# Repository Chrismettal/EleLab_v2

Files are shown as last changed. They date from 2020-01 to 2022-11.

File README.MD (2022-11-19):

# Elelab_v2 <!-- omit in toc -->

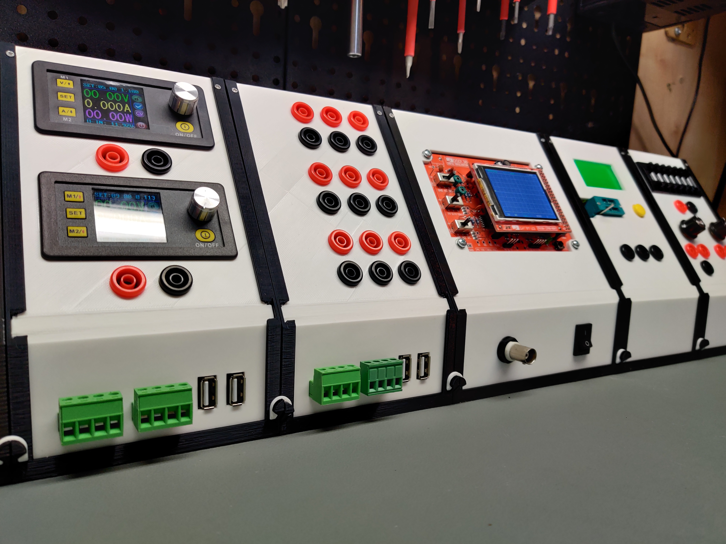
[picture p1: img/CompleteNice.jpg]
WholeSystem


## Table of contents <!-- omit in toc -->

- [Buying](#buying)
- [The concept](#the-concept)
- [The PCBs](#the-pcbs)
  - [Bus100 / Bus150](#bus100--bus150)
  - [PowerFeed](#powerfeed)
  - [Frontpanel\_a](#frontpanel_a)
- [The modules](#the-modules)
  - [Supplies](#supplies)
  - [Supply from ATX/SFX](#supply-from-atxsfx)
  - [Supply from XT60/Barrel](#supply-from-xt60barrel)
  - [Supply from Meanwell PSU](#supply-from-meanwell-psu)
  - [Supply from Bosch 18 V Battery](#supply-from-bosch-18-v-battery)
  - [Lab PSU fixed](#lab-psu-fixed)
  - [Lab PSU variable](#lab-psu-variable)
  - [Oscilloscope DSO138](#oscilloscope-dso138)
  - [Resistor decade](#resistor-decade)
    - [Performance](#performance)
  - [Component tester](#component-tester)
  - [Raspberry Pi](#raspberry-pi)
  - [Display](#display)
  - [Electronic Load](#electronic-load)
  - [Signal generator](#signal-generator)
  - [Audio amplifier / signal tracer](#audio-amplifier--signal-tracer)
  - [TS100 Soldering station](#ts100-soldering-station)
- [Tips and tricks](#tips-and-tricks)

This is a low cost, modular elctronics lab system for hobbyists.
The customizable modules include fixed and variable power supplies, measurement tools, component testers and much more.
Everything in here is done with open source software, including FreeCAD for all the 3d printable files and KiCAD for the PCBs.
I have made a set of modules already and am in the process of creating many more. Raw PCB project files, Gerbers and FreeCAD projects are all uploaded here for your customizing needs, while the finished modules are uploaded to Prusaprinters. Please be sure to upload any remix you do as it might be useful for others and especially myself!

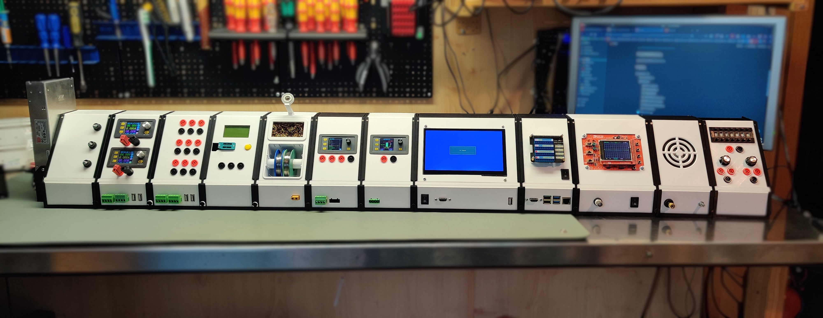
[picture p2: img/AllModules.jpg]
AllModules


The system features a set of backpanel bus PCBs as well as panel breakout PCBs. While the backpanel bus is not neccesary, it keeps the system modular, hot swappable and tidy. You can have the gerbers manufactured for cheap at your favorite chinese PCB house or just shoot me a message. I might have spares.

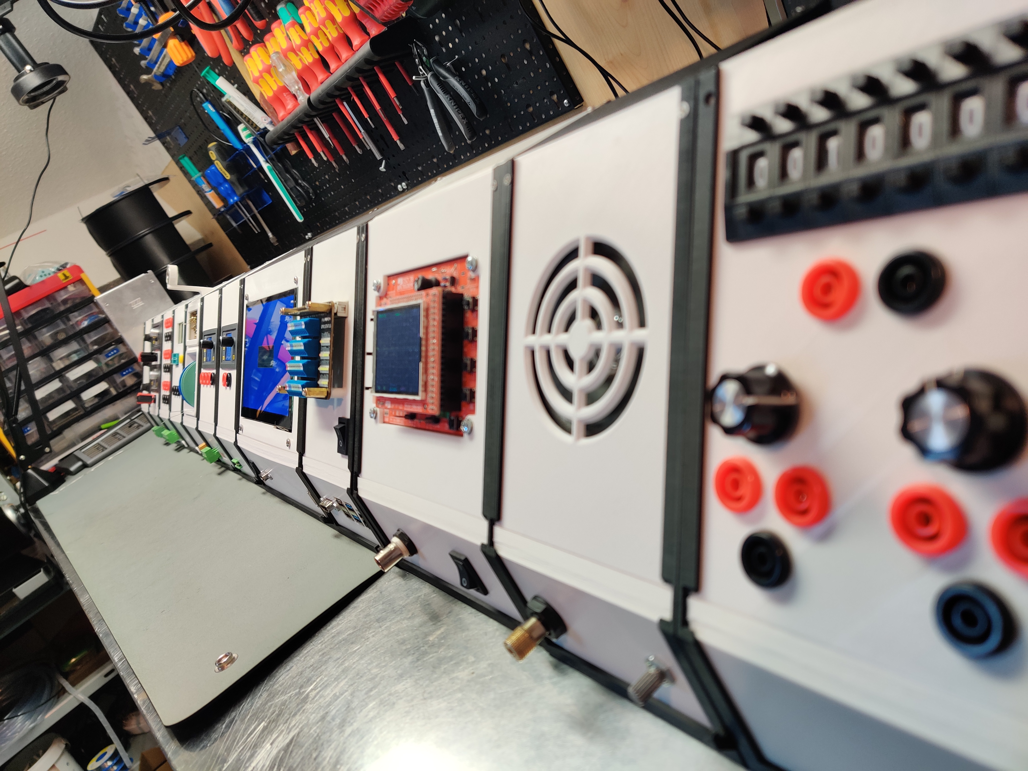
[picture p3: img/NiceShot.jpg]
NiceShot


Finished modules for printing yourself for any module can be found [here in the Prusaprinters collection](https://www.prusaprinters.org/social/13425-chrismettal/collections/14323).
For most of the modules a printbed of 160x160mm and 175mm of height is sufficient, but the ATX and SFX module require print bed sizes of up to 250mm width (Prusa MK2 and up dimensions). I printed all of the modules in PLA and just to speed things up i used a 0.6mm nozzle but that is not required at all.

Showcase

**If you like my work please consider [supporting my caffeine addiction](https://gitlab.com/Chrismettal#donations)!**

## Buying

All PCBs as well as 3D printed parts are now stocked at Tindie!



## The concept

The system consists of 3 basic sizes of modules, 100mm, 150mm and 200mm. For the 100mm and the 150mm frame there is a backpanel bus that interconnects the modules together for power delivery. The 200mm frame uses two of the 100mm PCBs.

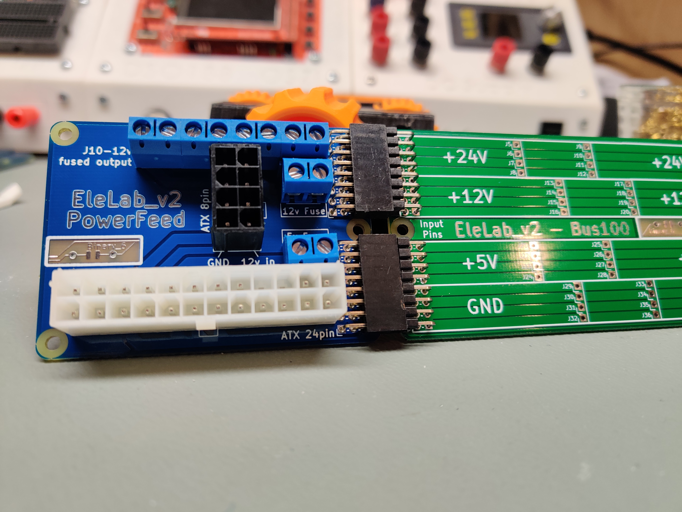
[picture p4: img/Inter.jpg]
Interconnects

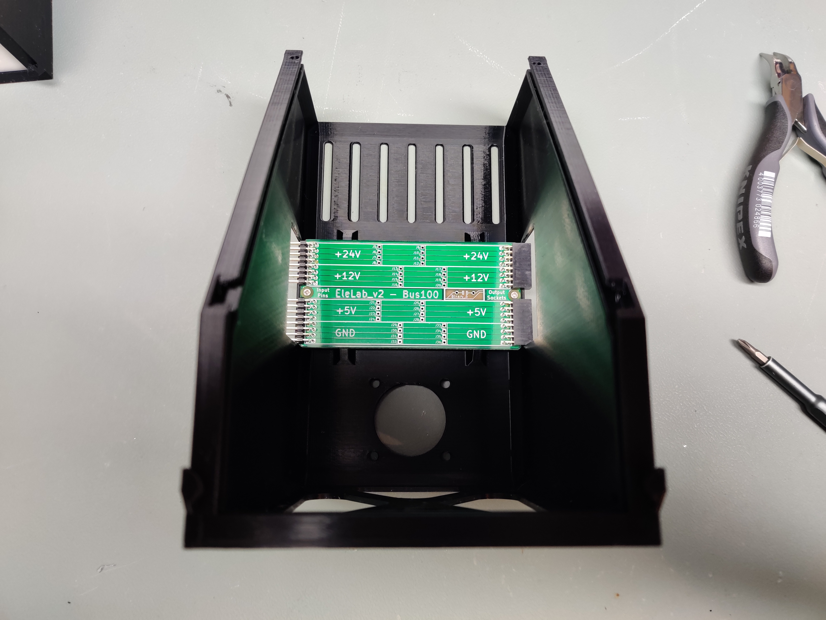
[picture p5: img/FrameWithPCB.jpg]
FrameWithPCB


For the modules we usually use one of the 3 base sizes and punch holes in the upper and/or lower front panel to suit our mounting needs. This can be done in FreeCAD by modifying the BaseXXX file or a finished module that best fits your new module. Alternatively you can also just edit the .stl files in the editor of your choice.

The backpanel bus is equipped to transfer 24 V, 12 V and 5 V (and GND, duh), which we feed into the system by one of the "Supply" modules. At the moment i made an SFX-PSU supply module (supplying 12 V and 5 V) and one with a 5.5mm barrel jack and XT60 jack (Using 24 V supplies and step-down converters for 12 V and 5 V). Both of these supply modules feature the PowerFeed PCB to feed into the backpanel bus. Because 24 V is rarely needed for most of the modules, the easiest and safest way to use this system is the SFX module, which just plugs into the PowerFeed PCB.

Obviously you can just run wires between the modules and omit the backpanel bus, but it will probably make me a little sad.

If you are using the bus, individual modules just plug into each other to form a single unit. 

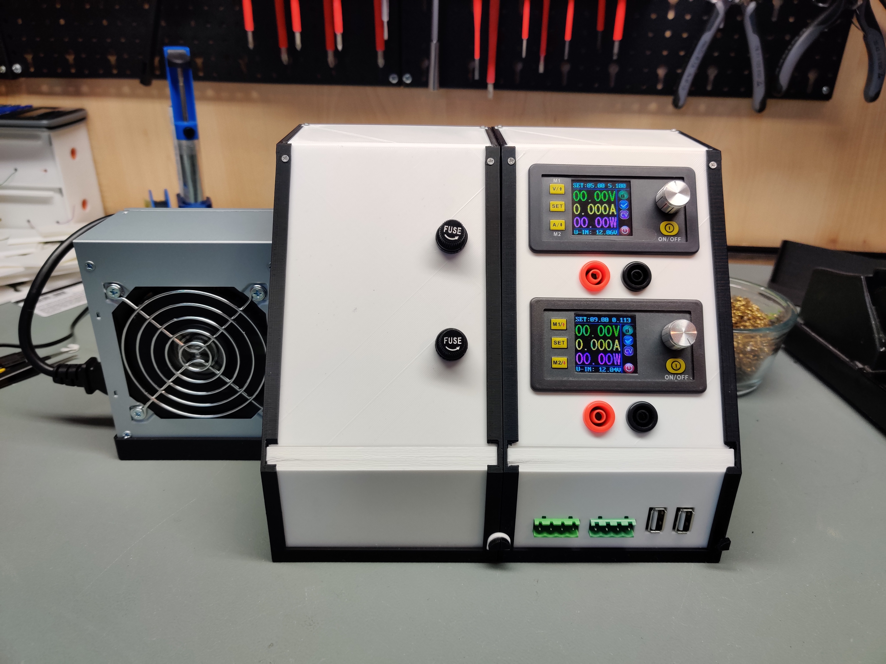
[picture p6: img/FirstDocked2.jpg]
FirstDocked2


With 2 little printed clips you can secure the modules together so they don't seperate during the occasional earthquake or lab-ragequit.

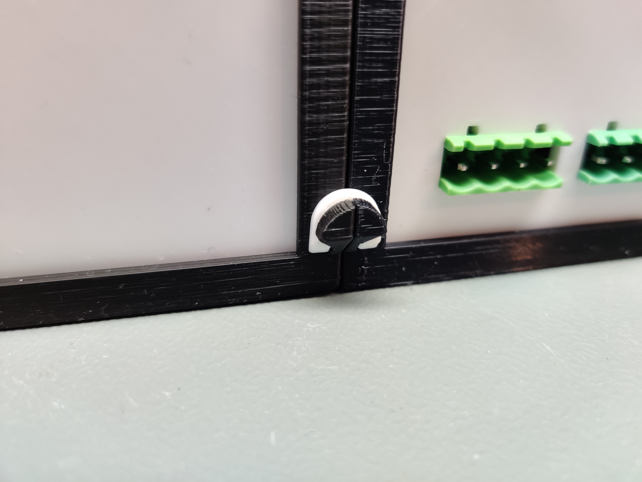
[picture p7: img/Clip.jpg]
Clip


Almost none of the 3d printable pieces require supports. The frame of each module has integrated supports at one position, that you will need to cut away after printing:

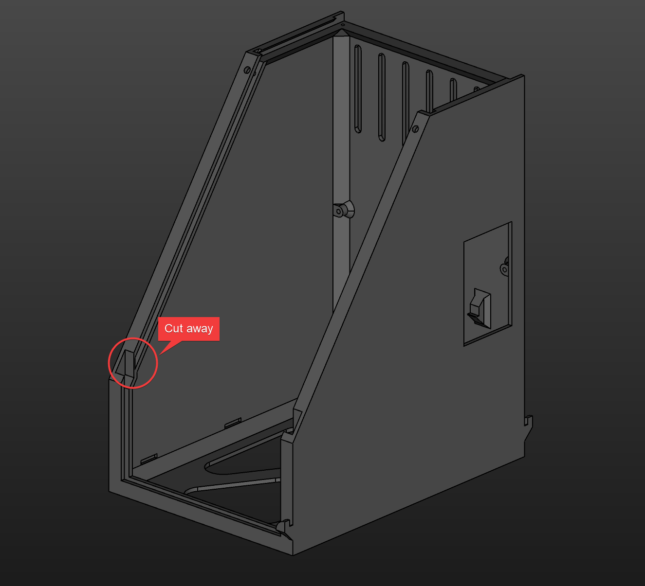
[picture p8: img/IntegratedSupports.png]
IntegratedSupports


## The PCBs

All of the PCBs can be cheaply manufactured in China (trust me, it's easier and cheaper than you think) or sometimes i even have spares left, if you shoot me a message.

### Bus100 / Bus150

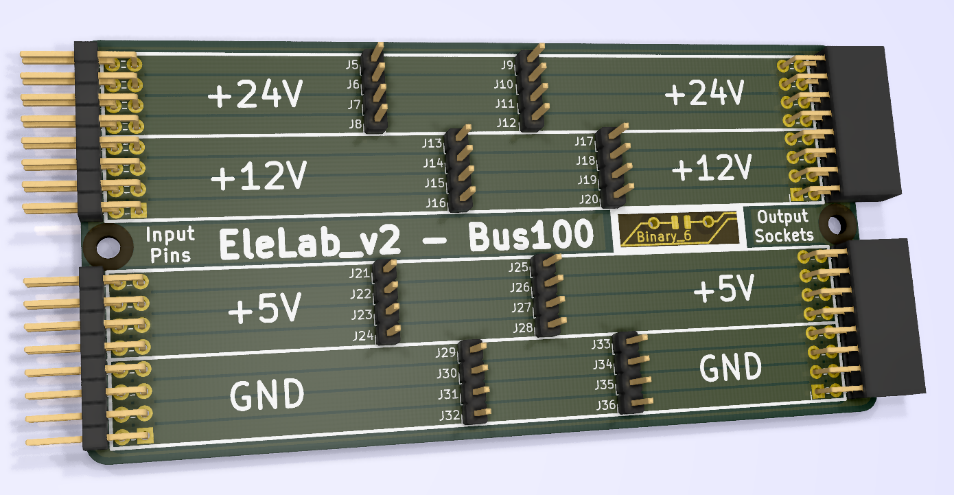
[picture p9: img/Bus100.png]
Bus100


This is the basic backpanel bus to link individual modules together. Though optional, it greatly enhances your experience in building this system.

**Parts:**

- 2pcs 2.54mm Pinheader right angle 2x8 female
- 2pcs 2.54mm Pinheader right angle 2x8 male

### PowerFeed

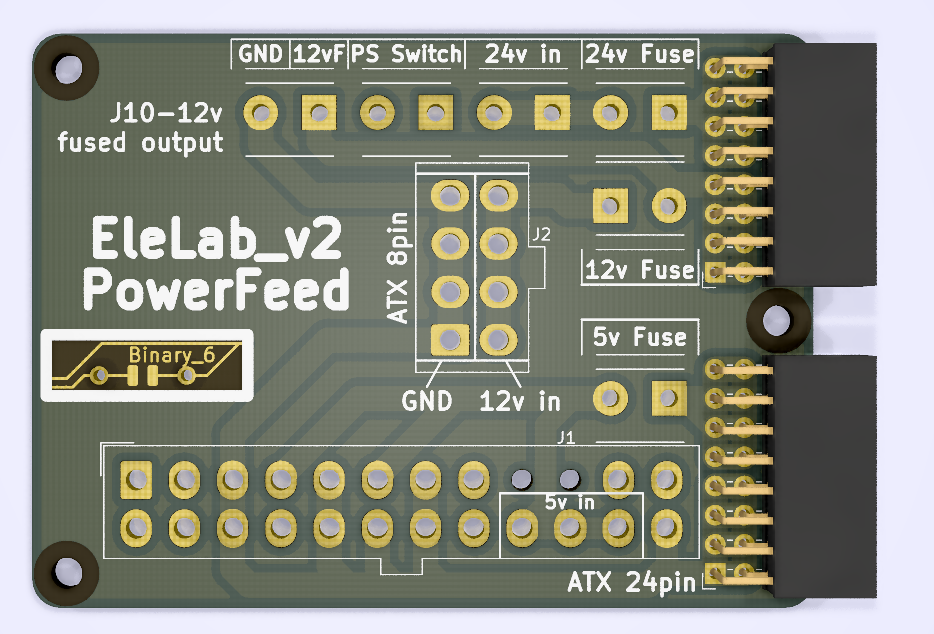
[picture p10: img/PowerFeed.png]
PowerFeed


This is the main infeed to connect your power supply to the backpanel bus and feed into the modules. It packs jacks to plug in your SFX supply, screw connectors for external fuses, and a breakout for the SFXs standby switch. Alternatively you could wire up your supplies directly to the spots marked as 24V, 12V and 5V respectively without using ATX connectors.

Using a PC supply, 12 V are supplied through either a 4 or 8 pin CPU header power plug. You cannot use the 8-pin GPU plug on your high end ATX PSU.

**Parts:**

- 24 Pin 4.2mm ATX Connector standing 
-  8 Pin 4.2mm ATX Connector standing
- 6pcs 5.08mm 2 Pin screw terminal (The blue cheap ones, optional though)

### Frontpanel_a

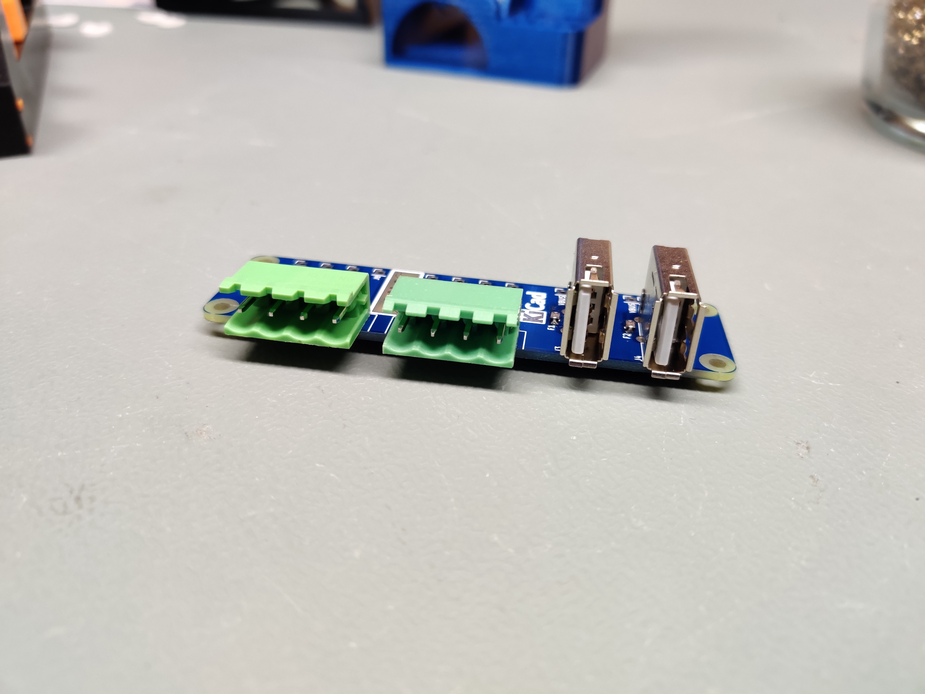
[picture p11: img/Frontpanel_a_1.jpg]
Frontpanel_a


Here we have the basic front panel breakout with industry style screw-plug connectors and USB jacks. The USB Jacks have a 0805 footprint in line with the 5 V rail so you can optionally install a tiny polyfuse in there. The data lines of each USB port are broken out so you can either use it for normal data transfer, or do whatever the best quick charge port configuration on the data lines is today. (for example bridging D+ and D- to put old Android phones into quick charge mode)

**Parts:**

- 2pcs 5.08mm pcb screw terminal block 4 pin
- 2pcs standing vertical USB Ports
- 2pcs 0805 polyfuse 1.1A (Or your desired amperage)

## The modules

### Supplies

No matter what Infeed you use, you should aim for around 100 - 150 W of power in general. I use a 24 V,  150 W power supply to infeed into my system. For PC supplies you should watch for the individual rail current, as a PSU might show 5 A of 12 V, but split over 5 rails, so if you only use one rail you will only get 1 A out of your PSU.

### Supply from ATX/SFX

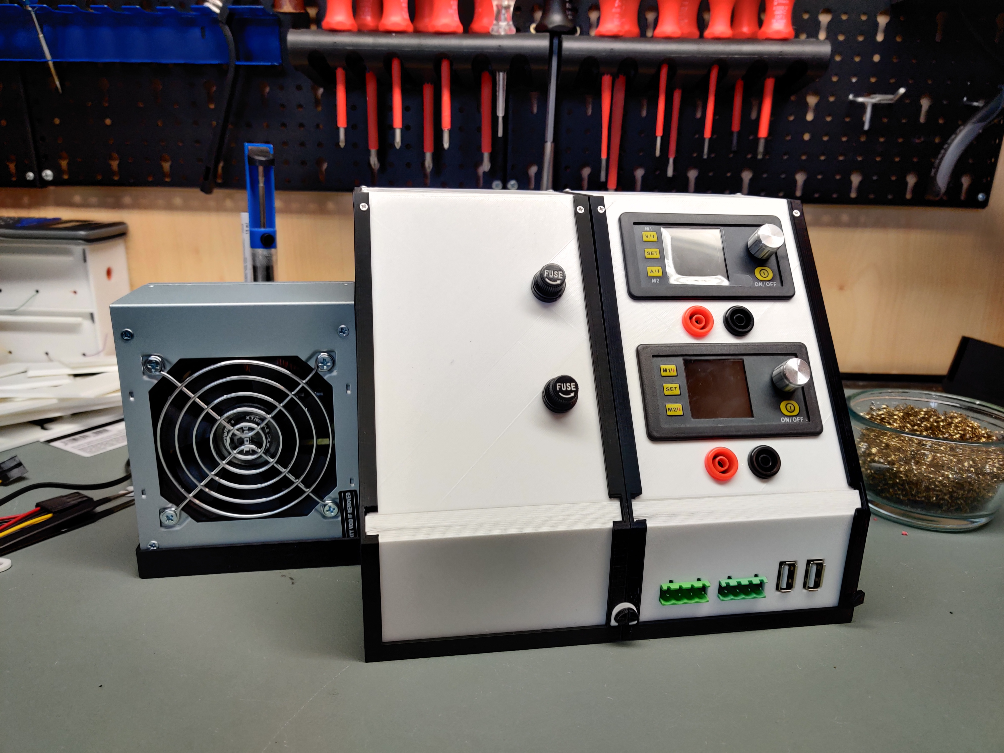
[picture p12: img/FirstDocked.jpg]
SFX


The easiest way to supply power to your EleLab is to use a regular ATX or SFX computer power supply. Using the PowerFeed PCB you can plug in the 24pin and 8pin connectors of your PSU directly into the backpanel bus. The module is preconfigured to use fuses for the 12 V and 5 V rails. You could install a switch for the PowerON PSU signal but i usually just bridge it completely so i switch the EleLab on and off by the main power switch on the back of the PSU.

Make sure the fan of your PSU is exposed as in the picture as not to overheat your poor PSU.

In the picture you see me build the SFX version of the module, the ATX version is printing at the time of writing this and is not tested yet.

**Parts:**

- PowerFeed PCB
- 2pcs screw in fuse holder panel mount
- SFX PSU of your choice
- 5pcs M2x8 self tapping screws

### Supply from XT60/Barrel

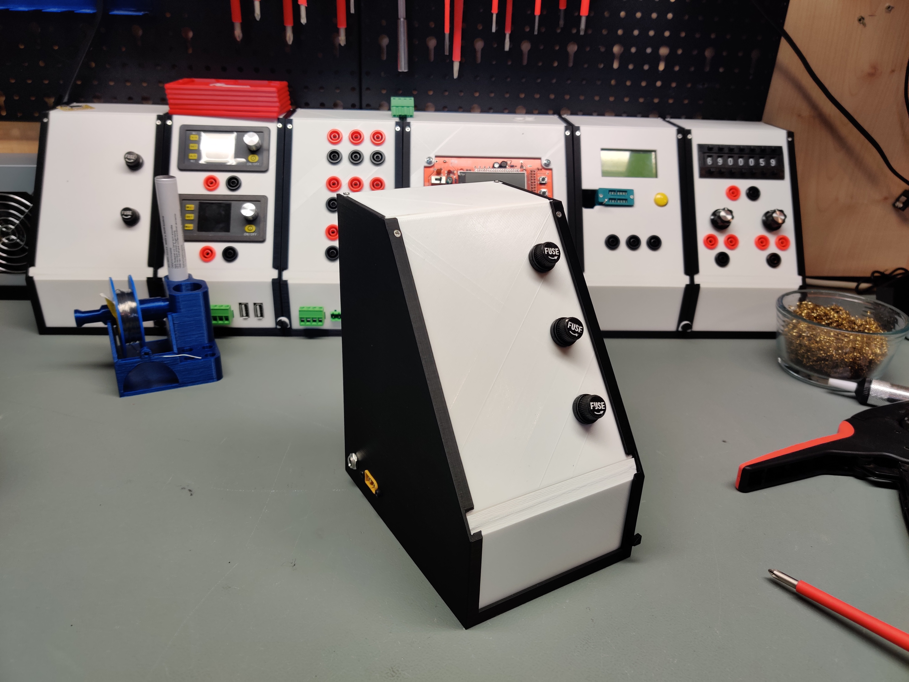
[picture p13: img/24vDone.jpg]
24vDone


With this supply module you can use any external 12 V or 24 V Power supply you want. You could even plug in some batteries with the XT60 jack!
This module however needs some beefy DC-DC step-down converters to create the 5 V rail, as well as the 12 V rail if you are using a 24 V supply. 
There is a printable tray that just snaps into the bottom, capable of carrying two of these types of step down converters:

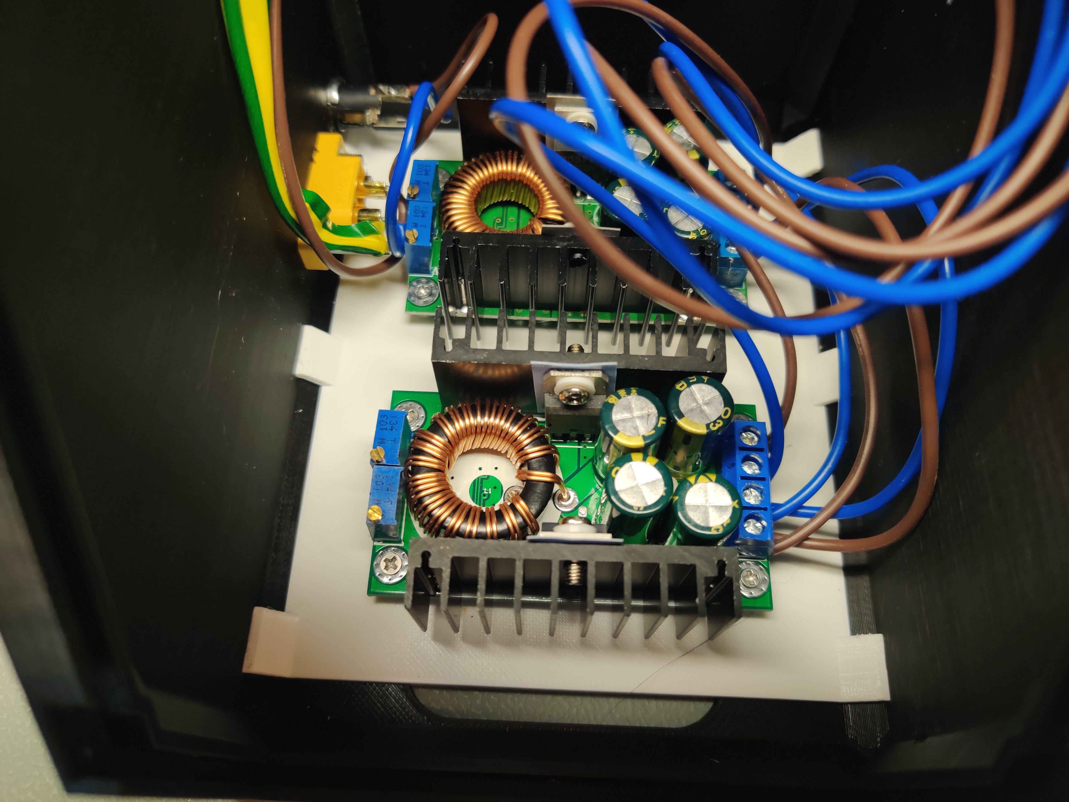
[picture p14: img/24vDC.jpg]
24vDC


These are readily available from china for a few bucks if you search for "step-down XL4016" on ebay. XL4016 is the name of the IC but it's the closest to a part number we get.

One of the converters will be set to output 5 V and one to output 12 V, when you supply the module with 24 V DC. This will give you all 3 voltages on the backpanel bus. The modules can also be configured for current limiting, which I set to 2 A each.

**Parts:**

- PowerFeed PCB
- 3pcs screw in fuse holder panel mount
- 2pcs DC-DC Step down converters XL4016
- 9pcs M2x8 self tapping screws

### Supply from Meanwell PSU

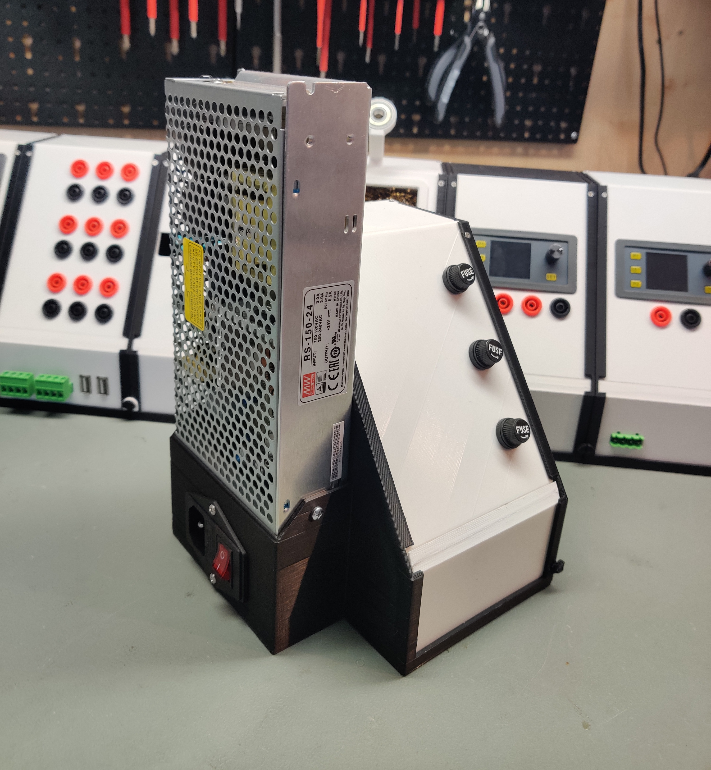
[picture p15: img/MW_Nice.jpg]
MWNice


Using the same step down converters, but this time using an internal PSU, the Meanwell module directly integrates a high quality supply into your EleLab. 
Since you will need to wire up mains voltage i can NOT show you how to do this. 
The Module uses an IEC C14 plug with integrated switch and fuse. Can't really find an exact name to google for.

The Meanwell supply should be a 24 V one, preferably the 150 W model, using the step down converters to step the voltage to 12 V and 5 V respectively.

**Parts:**

- PowerFeed PCB
- 3pcs screw in fuse holder panel mount
- 2pcs DC-DC Step down converters XL4016
- 9pcs M2x8 self tapping screws
- 4pcs M3x5 metric screws
- Meanwell RS-150-24
- IEC C14 Plug with switch and fuse

### Supply from Bosch 18 V Battery

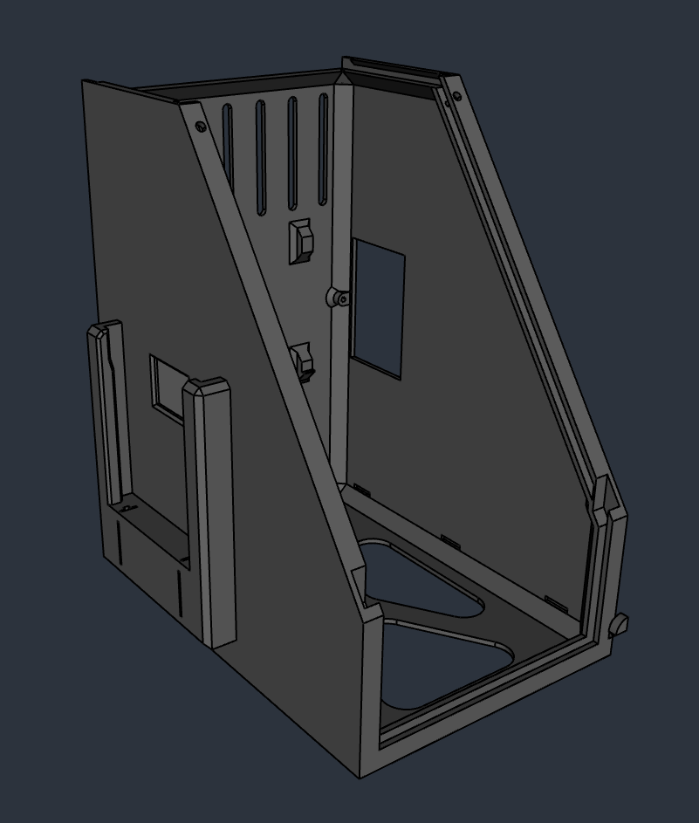
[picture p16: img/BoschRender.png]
BoschRender


BoschPurple

With this module you can use your 18 V Bosch batteries to supply a portable lab system. It also uses the same step down converters for rails of 18 V - 12 V and 5 V. Additionaly you will need two locking blade edge connectors. These are widely used in the car industry for confectionable plugs. The part number I found was “8KW048056-033” for a 6.3mm blade with 2.5mm² wire capacity.

Please note that 18 V Bosch batteries do NOT have over discharge protection built into the pack and can take damage if you run them below their specified "empty" point! Always watch the meter on your battery and make sure to use them in a healthy range. 

The edge connectors are slid in from the inside of the case and lock into place.

**Hint:** see also [standalone version](https://www.prusaprinters.org/prints/109595-bosch-18-v-battery-powerbank-power-supply)

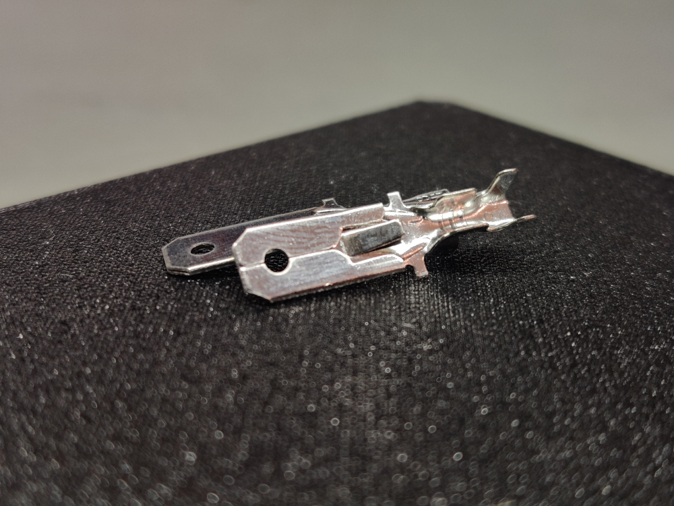
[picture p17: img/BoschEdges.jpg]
BoschEdges


**Parts:**

- PowerFeed PCB
- 3pcs screw in fuse holder panel mount
- 2pcs DC-DC Step down converters XL4016
- 9pcs M2x8 self tapping screws
- 2pcs “8KW048056-033” connectors
- Bosch 18 V battery

### Lab PSU fixed

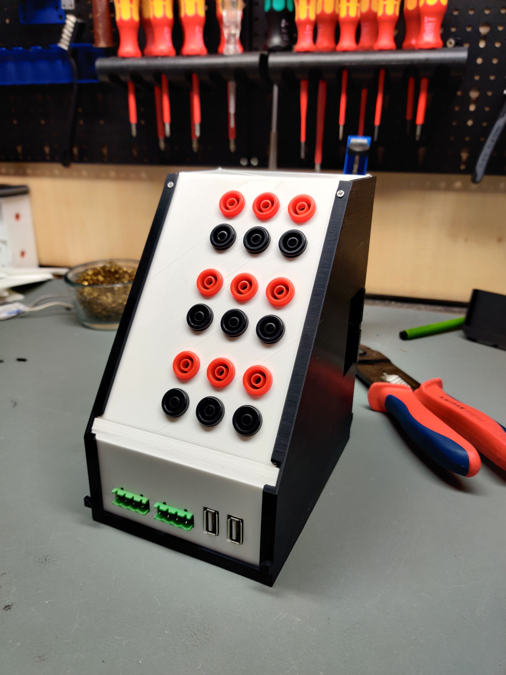
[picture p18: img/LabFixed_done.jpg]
LabFixed


The first actually usable module is a power breakout for your 5 V, 12 V and optionally 24 V rails. Using cheap chinese banana jacks with 12mm OD all rails can be accessed. In the front we use the Frontpanel_a PCB to have connections beside the banana jacks. Which terminal you connect to which rail is only dependend on your preferences. Obviously make sure to not reverse polarity on the USB ports or risk frying something. 

Here you can see the spagetthi wiring behind mine:

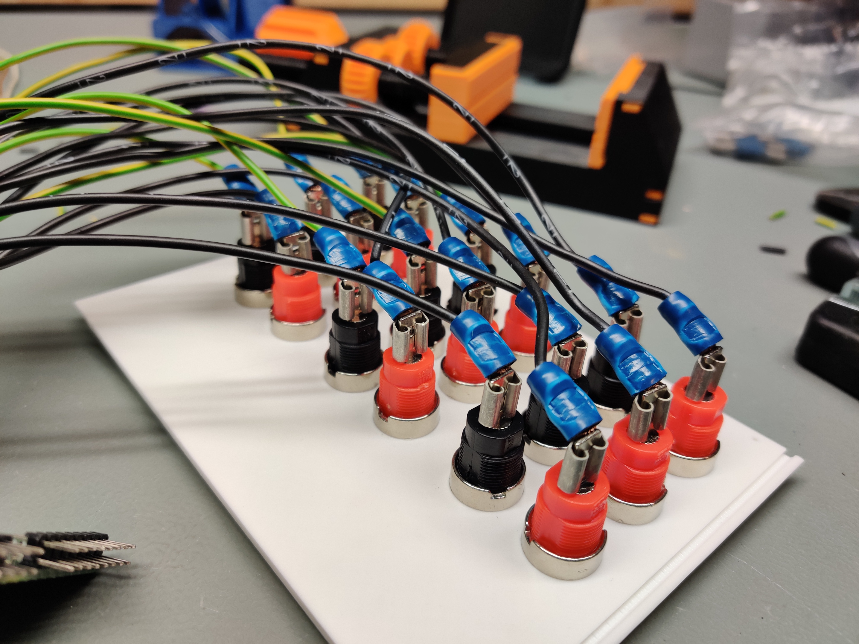
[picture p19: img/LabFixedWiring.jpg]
LabFixedWiring


Be sure to bend over your connectors as seen here as there is not extremely much room for the upper front panel to slide down:

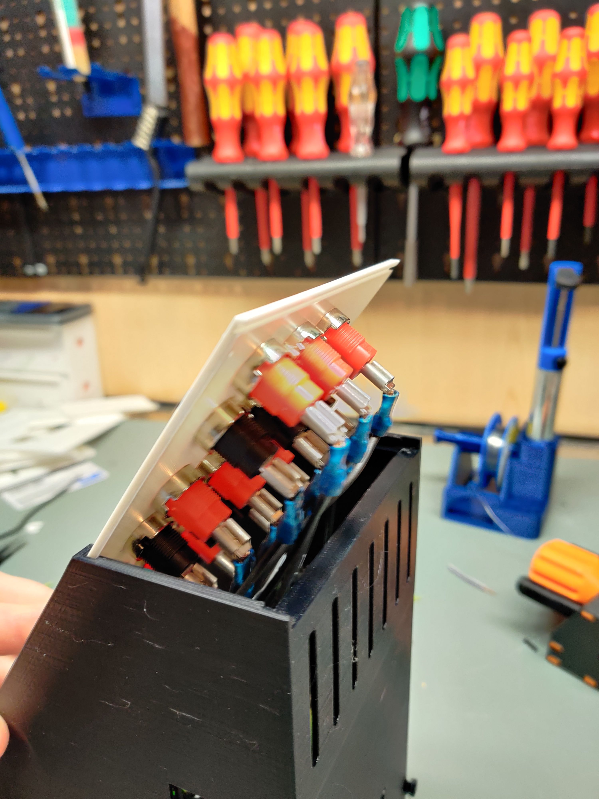
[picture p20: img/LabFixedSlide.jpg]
LabFixedSlide


The banana jacks are intentionally uncentered to make room for labeling on the left. I did not have time to create printable labels yet but i will get to it.

**Parts:**

- 12 or 18pcs banana jacks
- Bus100 PCB
- Frontpanel_a PCB
- 10pcs M2x8 self tapping screws

### Lab PSU variable

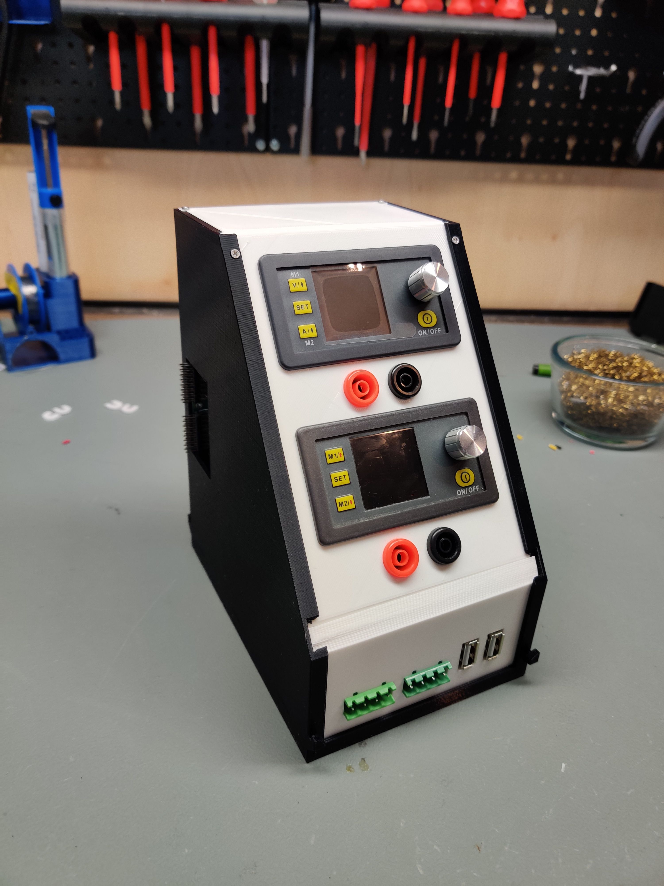
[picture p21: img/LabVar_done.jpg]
LabVar


Similar to the fixed supply we use a Frontpanel_a PCB here. The two variable step down converters (ebay is your friend again, TBDnameOfStepDown) are fed by either the 24 V or 12 V rail, depending on your infeed capabilities. Under each converter i put two banana jacks as the output, but also in parallel i wire up the industrial screw-plug connectors in the front to be outputs as well. If you are feeling adventurous you can also but the USBs behind the converters, but be vary that you can potentially but up to 24 V through the USB port then if you tell the converter to do it. The USB Jack will not be a happy charging port but rather something for debugging.

**Parts:**

- 2pcs DPS30005 or similar step down converter. You can get these in all voltage ranges under different names.
- 4pcs banana jacks
- Bus100 PCB
- Frontpanel_a PCB
- 10pcs M2x8 self tapping screws

### Oscilloscope DSO138

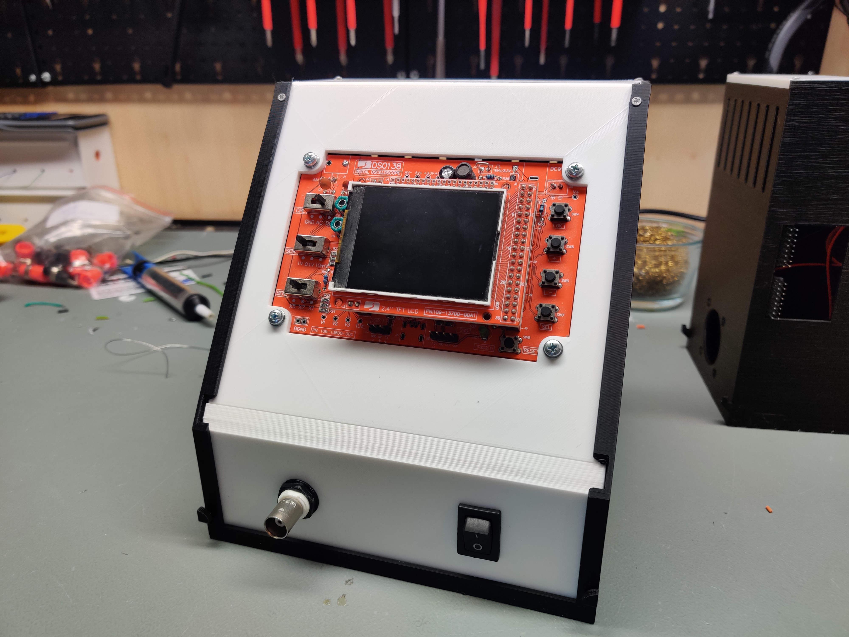
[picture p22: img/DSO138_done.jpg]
DSO138


The DSO138 is a great "Babies first oscilloscope". This super cheap thing is awesome if you don't wanna shell out serious cash if you are going to look at simple waveforms once per year and don't really care about accuracy a lot. Oftentimes i just wanna know IF something is even executing code and don't care HOW it is doing it so i often still fire up the DSO138.

You have to remove the old power jack of the DSO138 PCB and feed in power through a 13mmx19mm rocker switch out of the 12 V rail for this to fit. 4 x M3 screws with nuts fix the DSO PCB into the panel from the back. The BNC jack is also removed, a new frontpanel screw-in BNC jack is installed in the front, and wired up to where the original jack was. This is best done with a shielded cable (though i doubt you will see much difference with a DSO of this quality..)

**Parts:**

- DSO138 kit
- 12mmx19mm rocker switch
- Bus150 PCB
- 4pcs M3 screws and nuts
- 6pcs M2x8 self tapping screws

### Resistor decade

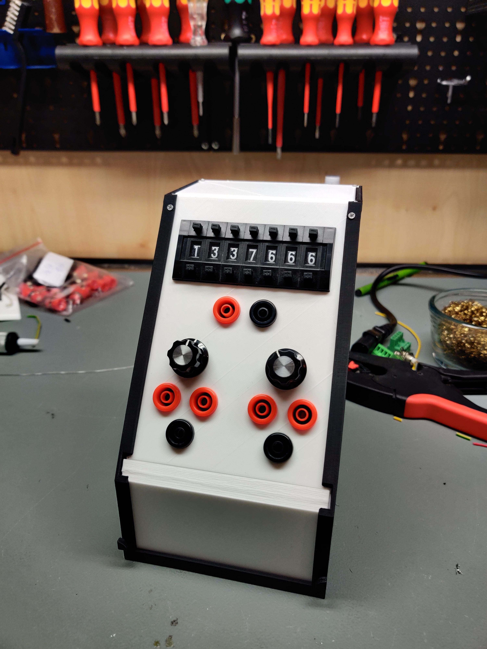
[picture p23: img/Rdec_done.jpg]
Rdec


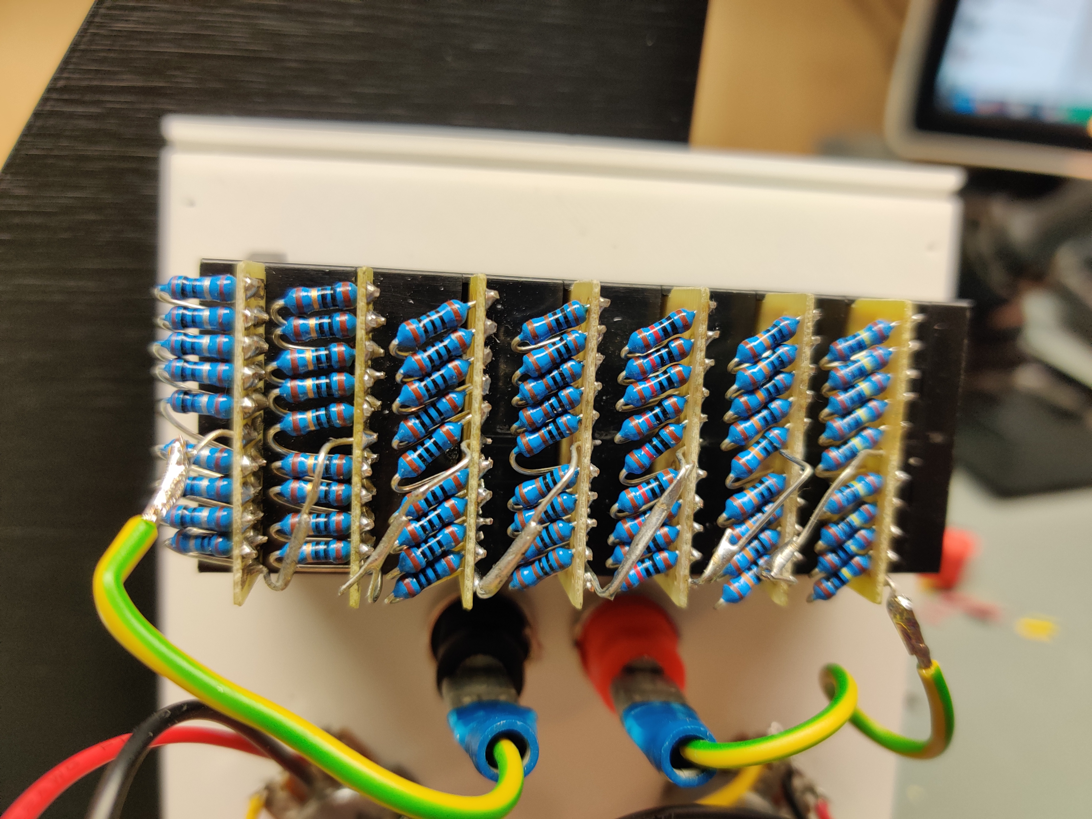
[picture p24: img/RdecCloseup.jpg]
RdecCloseup


Not really needing a backpanel this can safely be placed as the last piece of the EleLab as it does not even require power. Please follow your favorite guide on how to wire up your decade.

The 2 ends of the resistor decade are wired to two banana jacks. Also i installed 2 potentiometers into the panel, giving me some more flexibility. These are also just wired straight into 3 banana connectors.

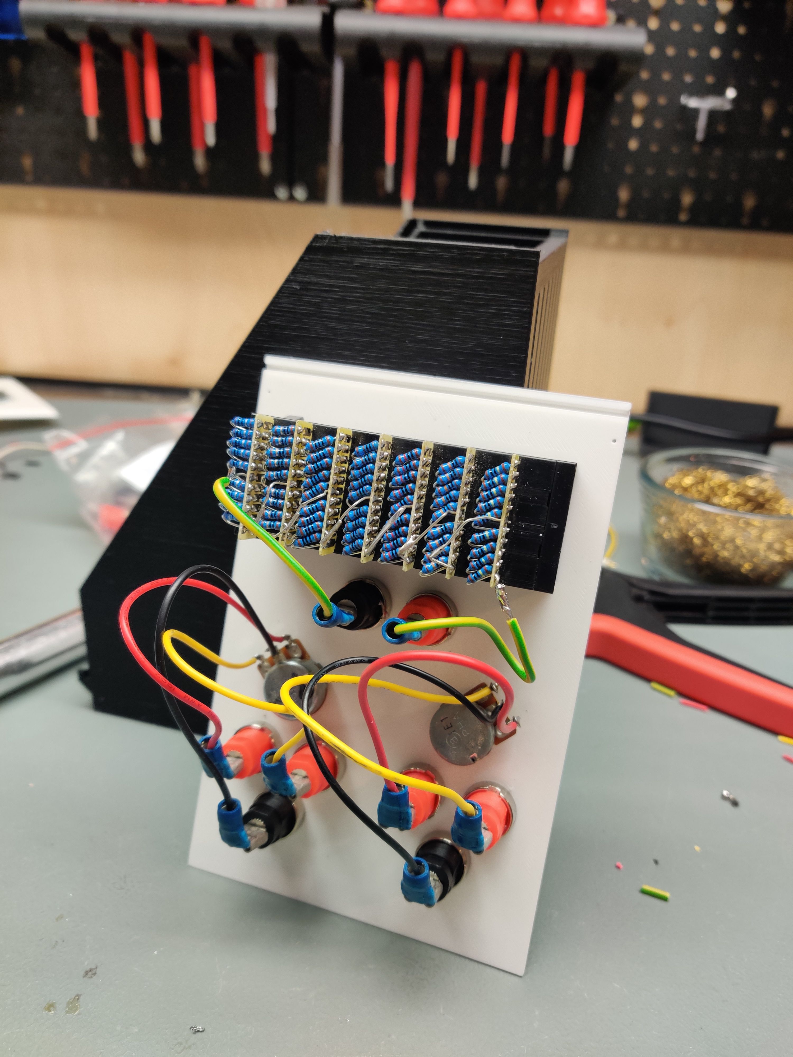
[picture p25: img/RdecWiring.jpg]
RdecWiring


Closing this module is tricky as well. You will need to NOT snap in the decade before sliding the front panel down:

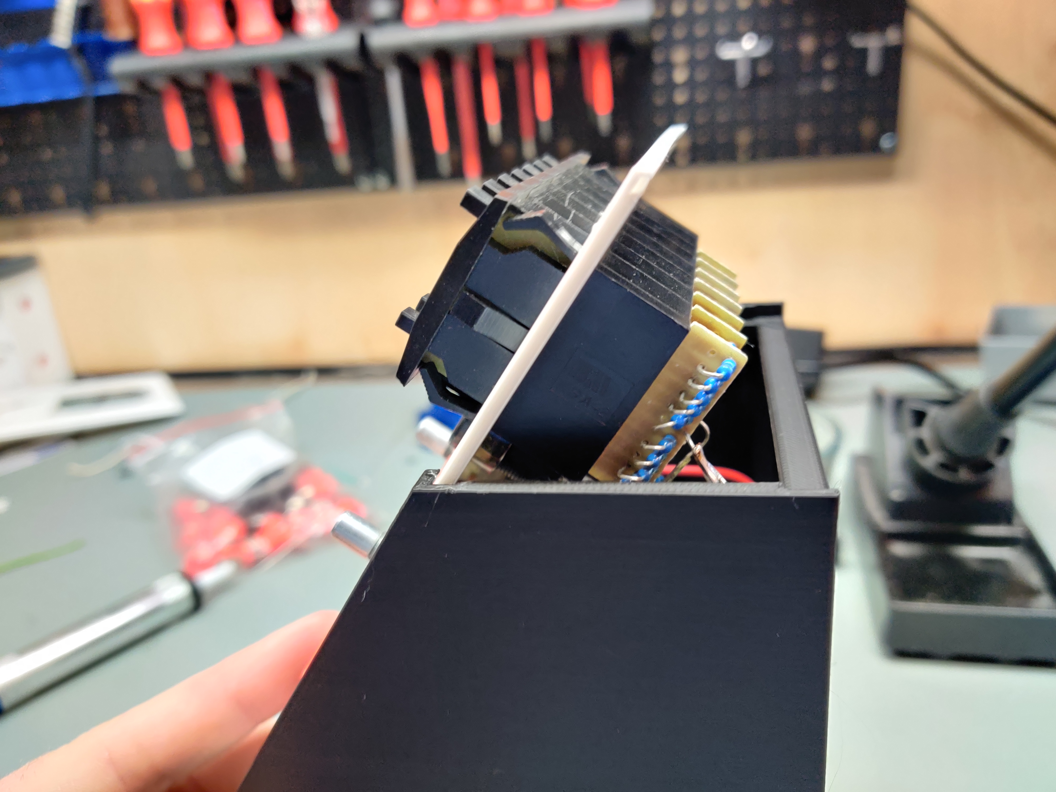
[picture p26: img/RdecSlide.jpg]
RdecSLide


A [schematic on how to wire the KSA-2 switches](PCB_CAD/EleLab_v2_RDecSchematic/RDecSchematic/RDecSchematic.pdf) is provided in [PDF](PCB_CAD/EleLab_v2_RDecSchematic/RDecSchematic/RDecSchematic.pdf) form, as well as a [KiCAD project](PCB_CAD/EleLab_v2_RDecSchematic/../../PCB_CAD/EleLab_v2_RDecSchematic/RDecSchematic/RDecSchematic.kicad_pro).

#### Performance

The high number of switch contacts will  cause a significant resistance error in the low range of `0-100R`, but for values above `100R` the accuracy raises greatly. The bad performance of the lower values skews the full range average / median, so seperate values for different ranges are provided.

| Range | Average Error % | Median Error % |
| --- | --- | --- |
| 1R - 100R  | 16.697 | 9.890 |
| 100R - 10M | -0.265 | -0.395 |
| Full range | 16.697 | 9.890 |

These raw values have been recorded with a Keysight 34461A using 4-Wire resistance measurement:

| Target [R]  | Actual [R]  | Error [R]  | Error [%] |
| --- | --- | --- | --- |
| 1.000 | 2.044 | 1.044 | 104.400 |
| 2.000 | 3.016 | 1.016 | 50.800 |
| 3.000 | 4.036 | 1.036 | 34.533 |
| 4.000 | 4.992 | 0.992 | 24.800 |
| 5.000 | 5.985 | 0.985 | 19.700 |
| 6.000 | 6.986 | 0.986 | 16.433 |
| 7.000 | 7.990 | 0.990 | 14.143 |
| 8.000 | 9.024 | 1.024 | 12.800 |
| 9.000 | 10.063 | 1.063 | 11.811 |
| 10.000 | 10.989 | 0.989 | 9.890 |
| 20.000 | 20.995 | 0.995 | 4.975 |
| 30.000 | 30.974 | 0.974 | 3.247 |
| 40.000 | 40.937 | 0.937 | 2.342 |
| 50.000 | 50.910 | 0.910 | 1.820 |
| 60.000 | 60.910 | 0.910 | 1.517 |
| 70.000 | 70.869 | 0.869 | 1.241 |
| 80.000 | 80.774 | 0.774 | 0.968 |
| 90.000 | 90.730 | 0.730 | 0.811 |
| 100.000 | 101.004 | 1.004 | 1.004 |
| 200.000 | 200.762 | 0.762 | 0.381 |
| 300.000 | 300.620 | 0.620 | 0.207 |
| 400.000 | 400.670 | 0.670 | 0.168 |
| 500.000 | 500.468 | 0.468 | 0.094 |
| 600.000 | 600.120 | 0.120 | 0.020 |
| 700.000 | 699.932 | -0.068 | -0.010 |
| 800.000 | 799.801 | -0.199 | -0.025 |
| 900.000 | 899.823 | -0.177 | -0.020 |
| 1000.000 | 999.342 | -0.658 | -0.066 |
| 2000.000 | 2000.430 | 0.430 | 0.022 |
| 3000.000 | 2998.200 | -1.800 | -0.060 |
| 4000.000 | 3999.820 | -0.180 | -0.004 |
| 5000.000 | 4998.400 | -1.600 | -0.032 |
| 6000.000 | 5998.460 | -1.540 | -0.026 |
| 7000.000 | 6996.200 | -3.800 | -0.054 |
| 8000.000 | 7993.540 | -6.460 | -0.081 |
| 9000.000 | 8991.460 | -8.540 | -0.095 |
| 10000.000 | 9957.250 | -42.750 | -0.428 |
| 20000.000 | 19904.500 | -95.500 | -0.478 |
| 30000.000 | 29845.600 | -154.400 | -0.515 |
| 40000.000 | 39806.000 | -194.000 | -0.485 |
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

**Parts:**

- 7pcs Thumbwheel switches KSA-2 with the ending caps
- 9pcs each of 1, 10, 100, 1k, 10k, 100k and 1M Ohm reistor
- 2pcs 9mm potentiometers of your choice, i used 5K B and 25K B
- 8pcs banana jacks
- Bus100 PCB
- 4pcs M2x8 self tapping screws

### Component tester

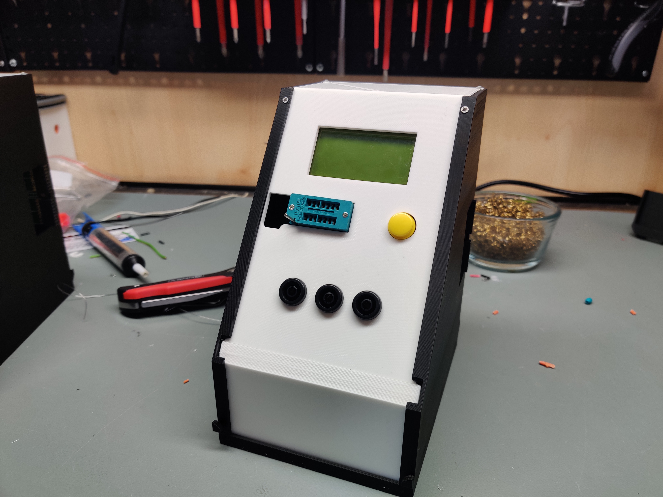
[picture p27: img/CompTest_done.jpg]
CompTest


You would not believe how much utility you will get out of these things. They are also very cheaply ordered from ebay, screw into the upper panel from the backside and can identify almost all of the components you throw at it. Usually these are fed by a 9 V battery and while you could till do that and have a battery lying inside the module i just feed it from the 12 V rail. Don't know about any longterm damages though.

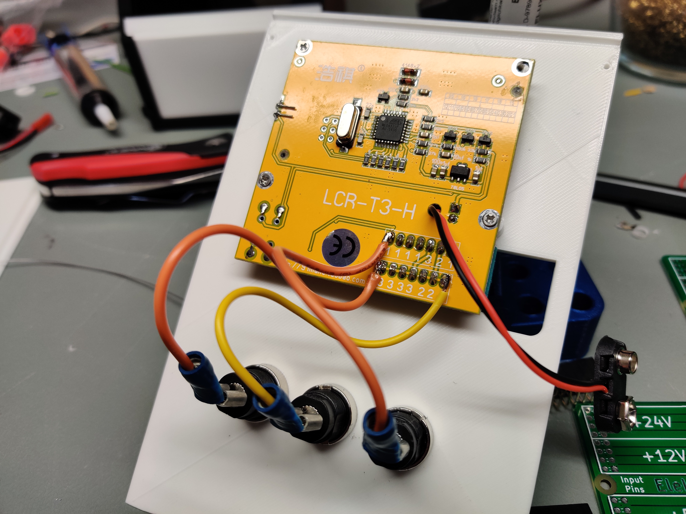
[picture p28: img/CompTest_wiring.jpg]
CompTestWiring


I wired 3 banana jacks right to the easiest to reach points numbered 1, 2 and 3.

**Parts:**

- Component Tester module
- 3pcs banana jacks
- Bus100 PCB
- 9pcs M2x8 self tapping screws

### Raspberry Pi 

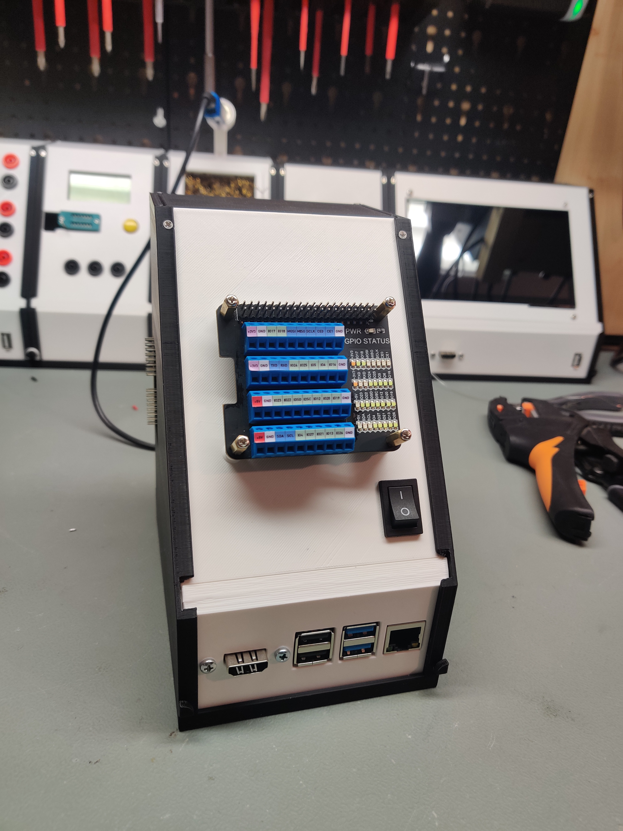
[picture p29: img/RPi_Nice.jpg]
RPi


Raspberry Pi carrier with USB / Ethernet / HDMI and GPIO broken out, including HAT compatible front plate. I use a "GPIO screw terminal hat" as the front plate to easily break out all GPIOs, but still be able to connect a GPIO extension cord down to a breadboard, or stack more HATs on top.

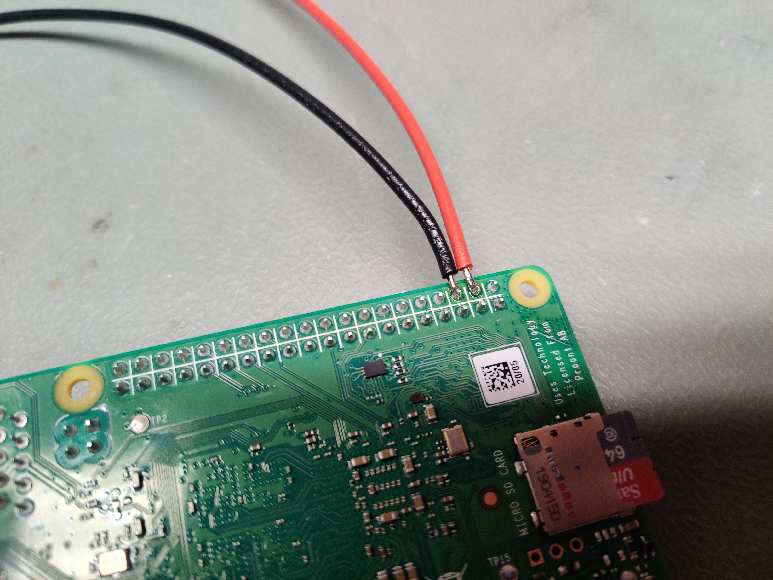
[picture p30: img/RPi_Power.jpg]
RPiPower


The Pi is powered through the bottom side of the GPIO header since the top side is taken by the GPIO extension cord. 5 V from the back panel is directly applied through a rocker switch.

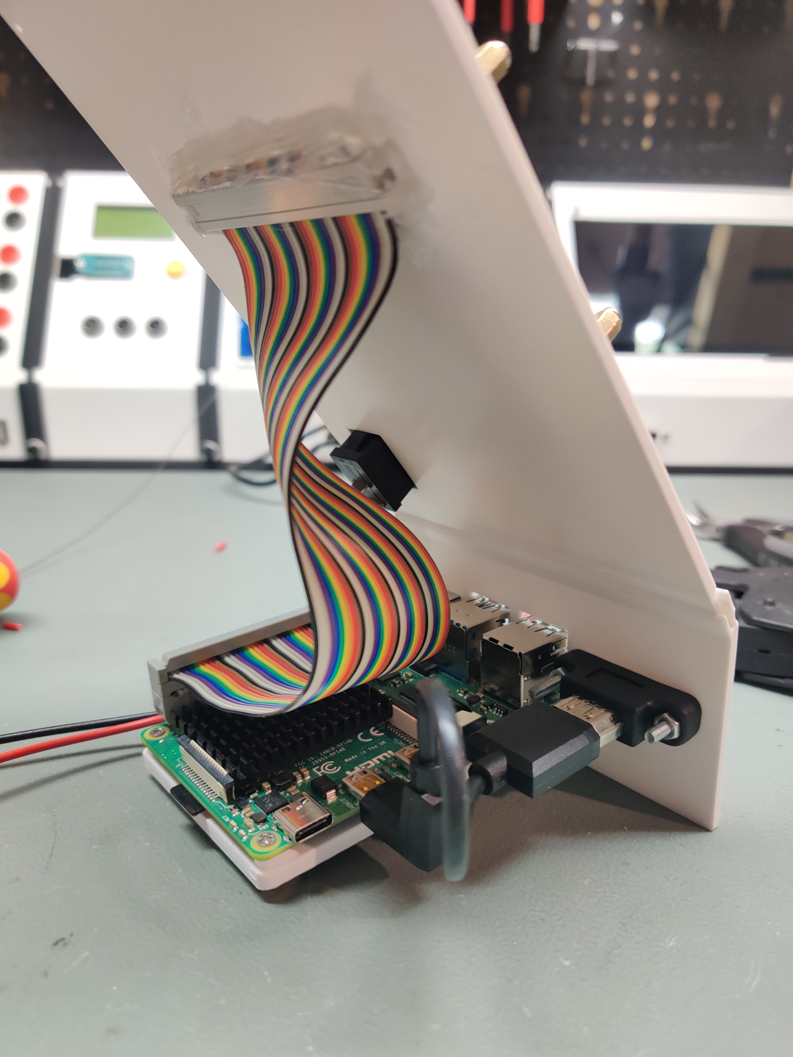
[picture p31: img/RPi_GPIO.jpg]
RPiWiring


Make sure to plug in the GPIO extension as shown. This is basically the only way it will be long enough and also the only way where the new header in the upper panel will be right side up and not mirrored.
I recommend mounting a breakout / extension HAT as shown to have easy screw terminal access to all GPIO pins, but still be able to plug HATs on top of it. Mounting the HAT now, screwing in PCB standoffs and THEN hot-snotting the extension cord in place from the back makes mounting much easier.

You will also need an angled mini-HDMI to HDMI cable. Make sure it is angled the correct way since it won't fit otherwise.

**Parts:**

- Raspberry Pi
- HDMI Female - Female front panel connector
- GPIO extension cord male-female about 150mm
- Bus100 PCB
- 12mmx19mm rocker switch
- angled short mini-HDMI to HDMI cable
- optionally - GPIO breakout board of your choice

### Display

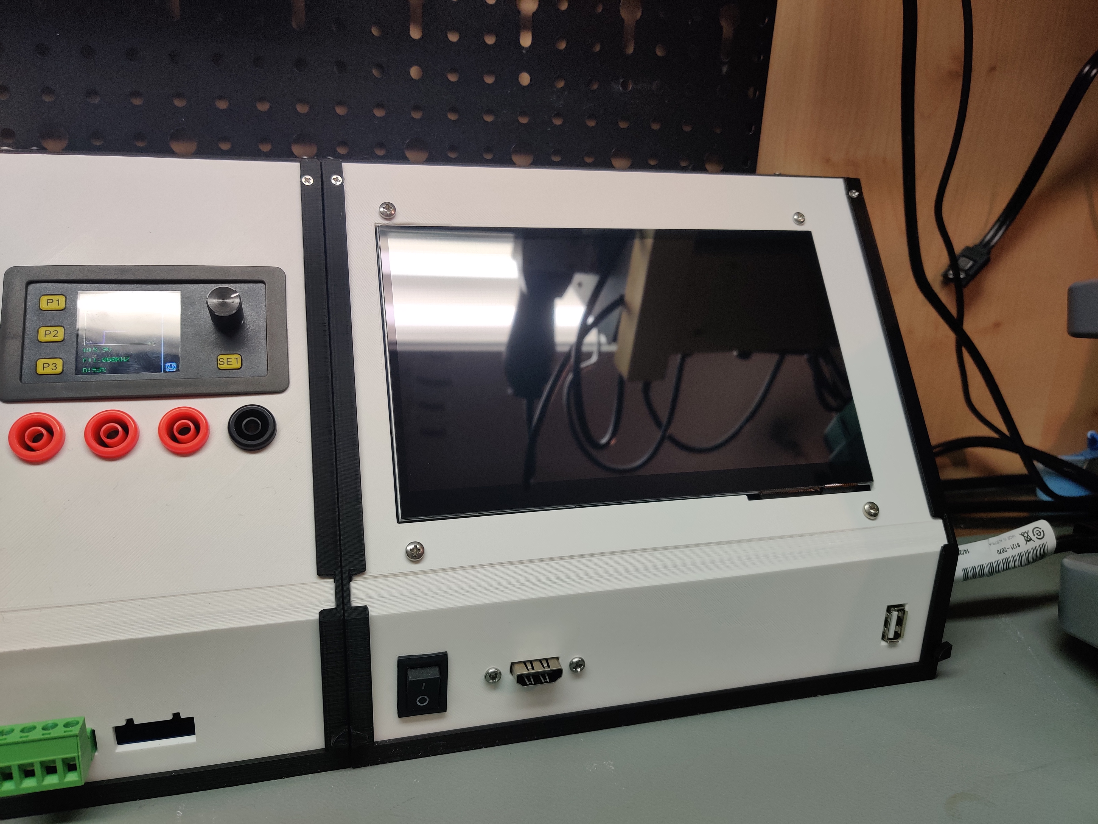
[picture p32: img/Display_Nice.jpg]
DisplayNice


7 Inch HDMI Display with touchscreen. HDMI and USB broken out.

**WARNING:** currently, to use the same frontpanel, a USB-A plug is used for the touchscreen. Usually you would use a Micro USB, USB C, or USB-B header for this breakout. To actually use the touchscreen for now you would have to use an USB-A to A cable, until someone made a frontpanel for USB-C or Micro USB (might be me idk).
If you are using the Frontpanel_A be sure to NOT populate the fuse, so you disconnect the 5 V rails of both USB devices.

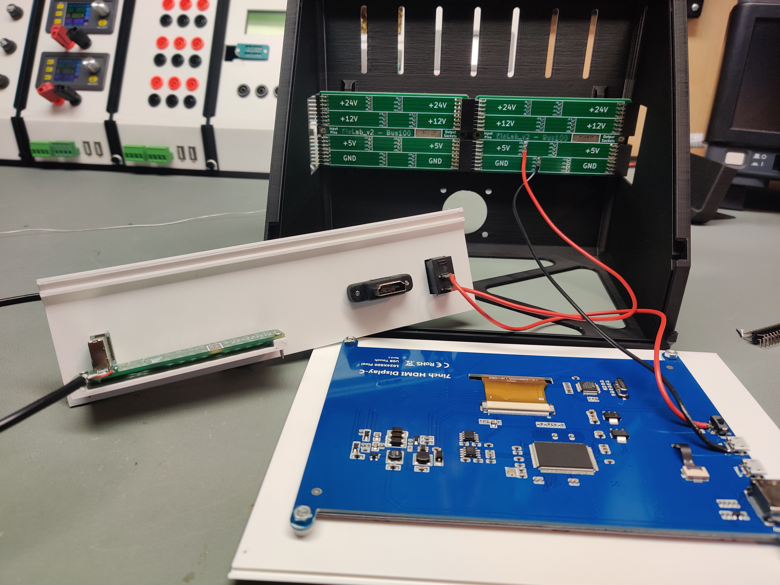
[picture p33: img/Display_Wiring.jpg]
DisplayWiring


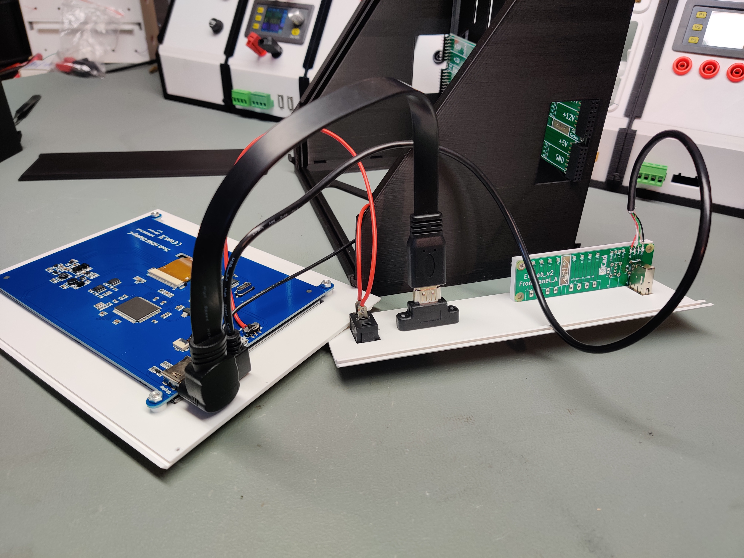
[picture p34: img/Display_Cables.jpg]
DisplayCables


You will need a short angled HDMI cable and an angled USB-Micro cable like shown, as straight cables won't fit in the frame. The HDMI cable connects directly to a female-female HDMI front panel mount, while the USB cable is cut open and soldered to the Frontpanel_A.

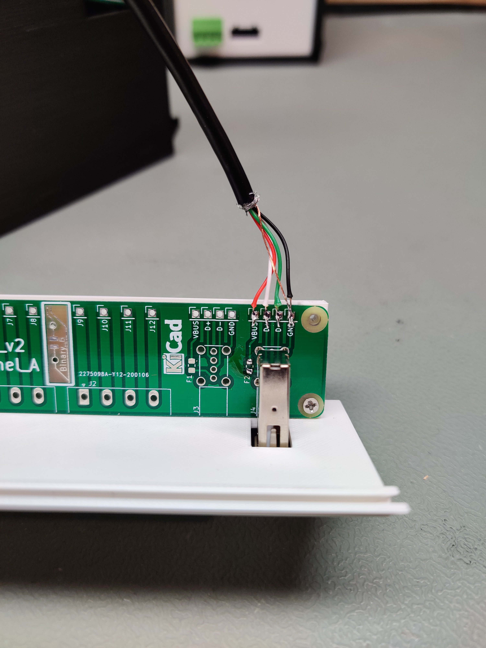
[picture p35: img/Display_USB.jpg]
DisplayUSB


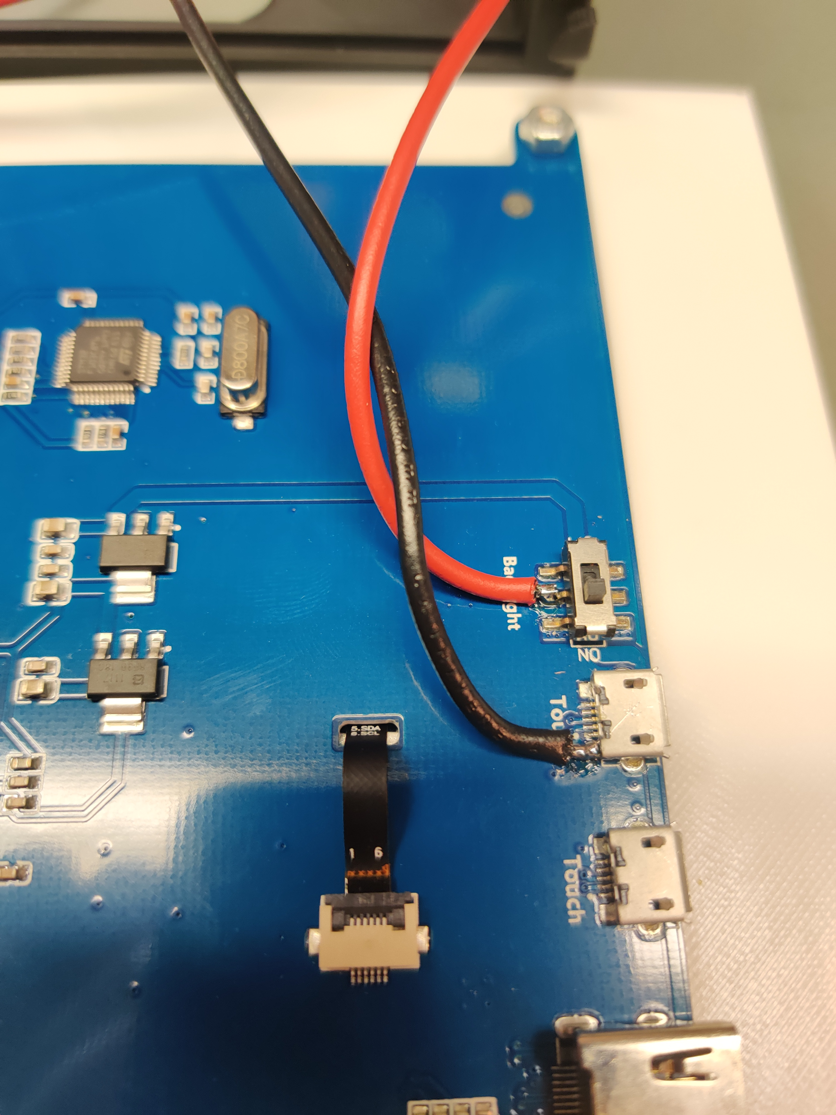
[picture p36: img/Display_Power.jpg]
DisplayPower


The display is powered with 5 V through a rocker switch, soldered directly to the shown points on the board. I used the GND of one of the Micro USB plugs, and 5 V is applied to the middle of the display switch. You could also cut open a second USB cable and use that, but I did not want to waste these precious angled cables

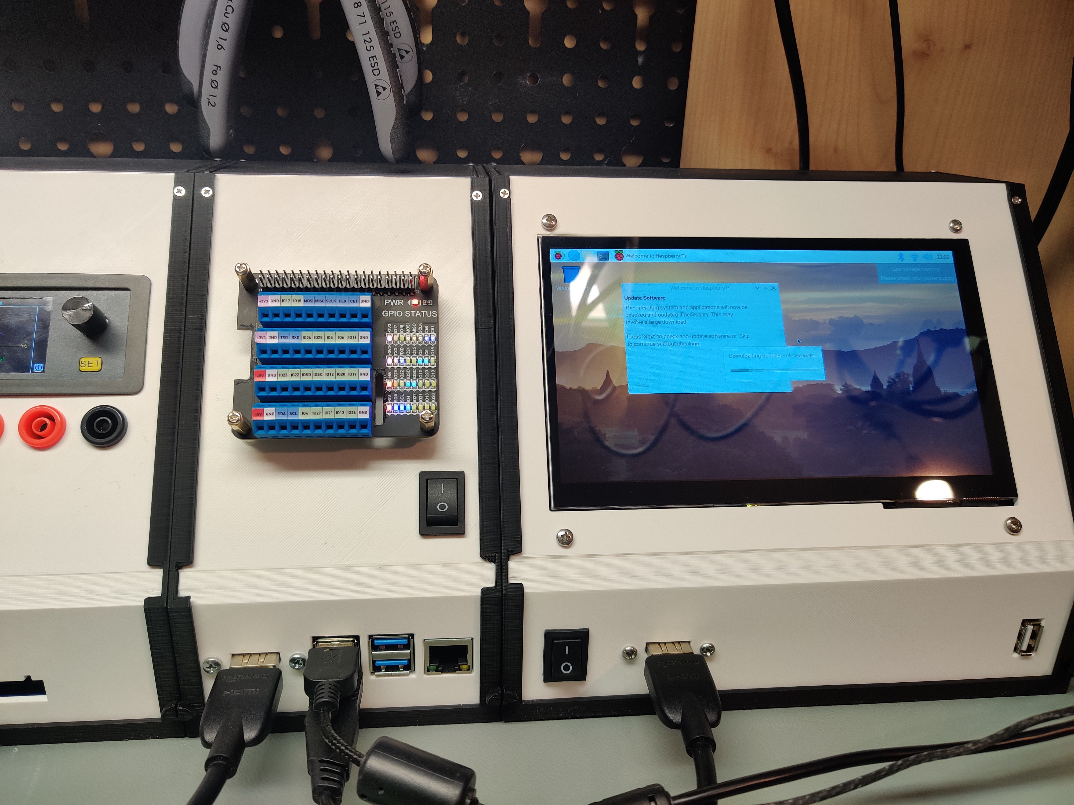
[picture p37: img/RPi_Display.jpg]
RPiDisplay


This modules works great in conjunction with the RPi module!

**Parts:**

- Waveshare 7 inch HDMI Display C
- 2 x Bus100 PCB
- Frontpanel_A PCB with only one USB jack mounted
- 12mmx19mm rocker switch
- 8pcs M2x8 self tapping screws
- 6pcs M3x15 metric screws with nuts
- female-female HDMI front panel connector
- angled HDMI cable
- angled micro USB cable

### Electronic Load

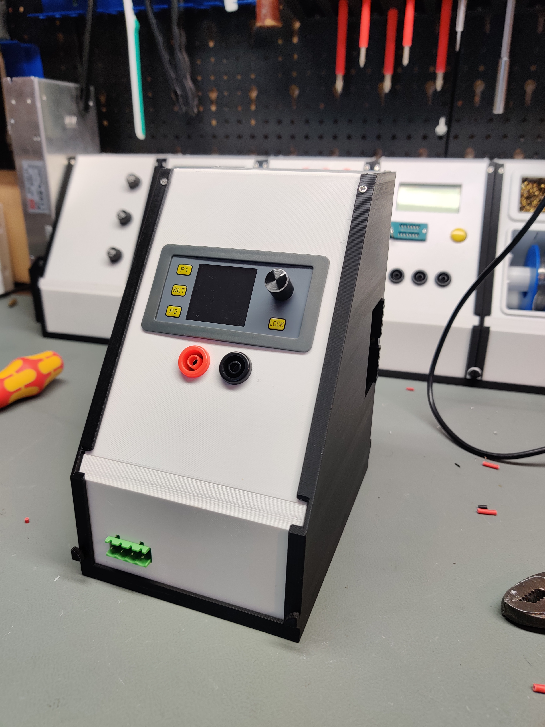
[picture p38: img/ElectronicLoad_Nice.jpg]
ElectronicLoadNice


30 W electronic load module, don't know everything it can do yet, but you'll figure it out.
This module actually uses the fan opening in the back of the frame since it does generate some heat (duh).
It does have 4 wire measurement but I chose to omit this here to avoid confusion. For loads this small and modules with this low accuracy I did not see the benefit. The 4 wire measurement is therefore connected on the inside to the 2 terminals directly:

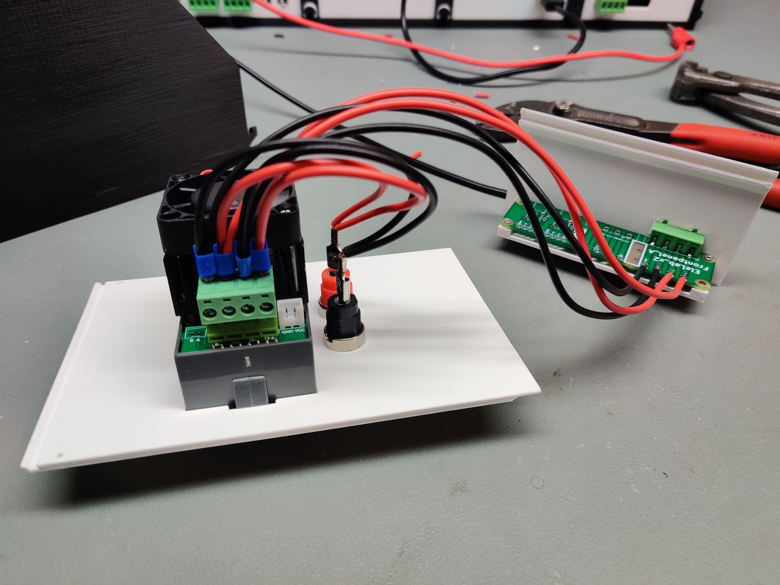
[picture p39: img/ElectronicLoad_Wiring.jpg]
ElectronicLoadWiring


**Parts:**

- WEL3005 or similar electronic load module
- Bus100 PCB
- Frontpanel_A PCB
- 8pcs M2x8 self tapping screws
- 30mm fan

### Signal generator

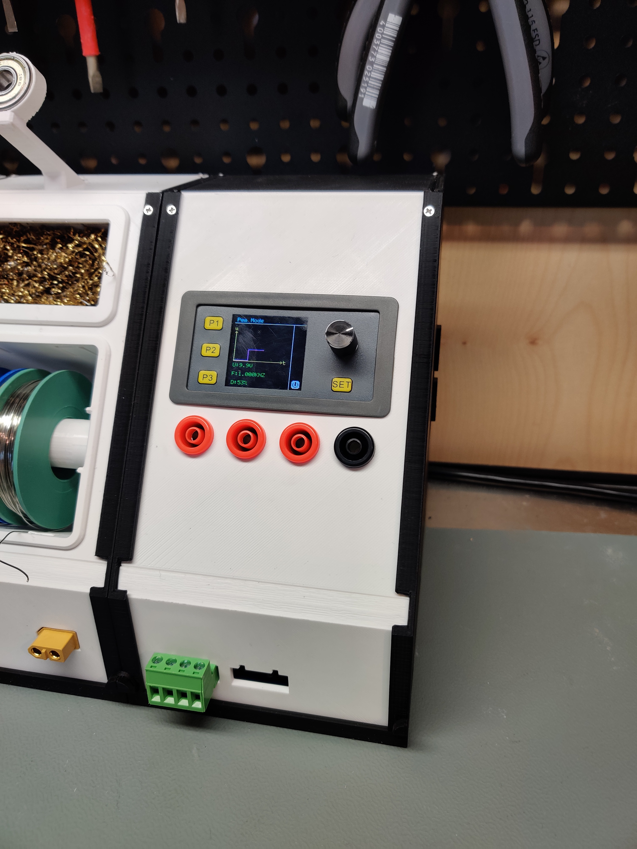
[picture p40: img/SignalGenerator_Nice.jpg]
SignalGeneratorNice


4-20mA / 2-10 V / PWM signal generator. All contacts are broken out to banana jacks as well as the front panel in the order of your choice.

**Parts:**

- WSFG-06 or similar signal generator module
- Bus100 PCB
- Frontpanel_A PCB
- 8pcs M2x8 self tapping screws

### Audio amplifier / signal tracer

PAMNice

Mono speaker with tiny amplifier mainly for audible signal tracing. Music won't sound good on this device so please don't expect a workshop audio system in your lab. Left and right inputs are shorted together and the right input on the PAM is pulled to GND so we only use the left input in mixed-down-mono configuration.

The speaker is only glued in to accomodate all speaker sizes, so any speaker with below around 80mm diameter will work. 3-4 W is a typical power for speakers of these sizes.

PAMResistors

Since this device is only mono, you should connect both channels together to one PAM input. For this, use two resistors (anything between 3k3 and 10k is probably fine) as shown here.

PAMWiring

I put the output of both resistors to both channels so it does not matter which channel I use for the speaker output. I also put some heatshrink over the two resistors for some mechanical stability.

**Parts:**

- PAM8403 amplifier module with switching pot
- Bus100 PCB
- Some speaker - 75mm outer dia in my case
- 1/4 (6.35mm) Inch stereo jack

### TS100 Soldering station

TS100Nice

Soldering "station" for TS100 soldering irons. The Iron can be kept in an ugly holder up top, powered by the XT60 plug below. The upper front plate is done with two snap-in buckets since the buckets are too deep to be sled in from the top fully. The upper bucket is meant for a soldering sponge and the lower bucket can keep your solder wire. I would either print the upper one in something heat resistant like PC or just use some aluminium tape on the inside so you don't burn the plastic with the hot tip.

The XT60 plug is snapped in from the front after soldering some heavy wires to it. Afterwards you can solder the wires to the Bus100 PCB (24V). 

The skateboard bearing is just pressed in the top. If it's too loose you can also glue it in.

Both buckets snap in from the front as the last item.

Make sure to use this module "more to the left" of your EleLab, since it draws quite a lot of power, which you probably don't want to travel through 20 modules.

**Parts:**

- Bus100 PCB
- 608ZZ skateboard bearing for the holder
- XT60 female plug

## Tips and tricks

You can keep the wires nice and short if you put together the modules as follows:

### Wire up your frontpanels  <!-- omit in toc -->

LabVar_0

LabVar_1

### If your wires are long enough you can place and screw in your backpanel bus already <!-- omit in toc -->

LabVar_2

### Slide on the UPPER PANEL FIRST but don't do it all the way yet. <!-- omit in toc -->

LabVar_3

### Slide in the LOWER PANEL now. You will see how this requires much less wiring you need for this. <!-- omit in toc -->

LabVar_4

### Now slide on the upper panel fully. <!-- omit in toc -->

LabVar_5

### If you have really short cables running from your front panels to your backpanel bus you can also slide in the frontpanel first and only then screw the backpanel bus into the frame. <!-- omit in toc -->

TightScrew

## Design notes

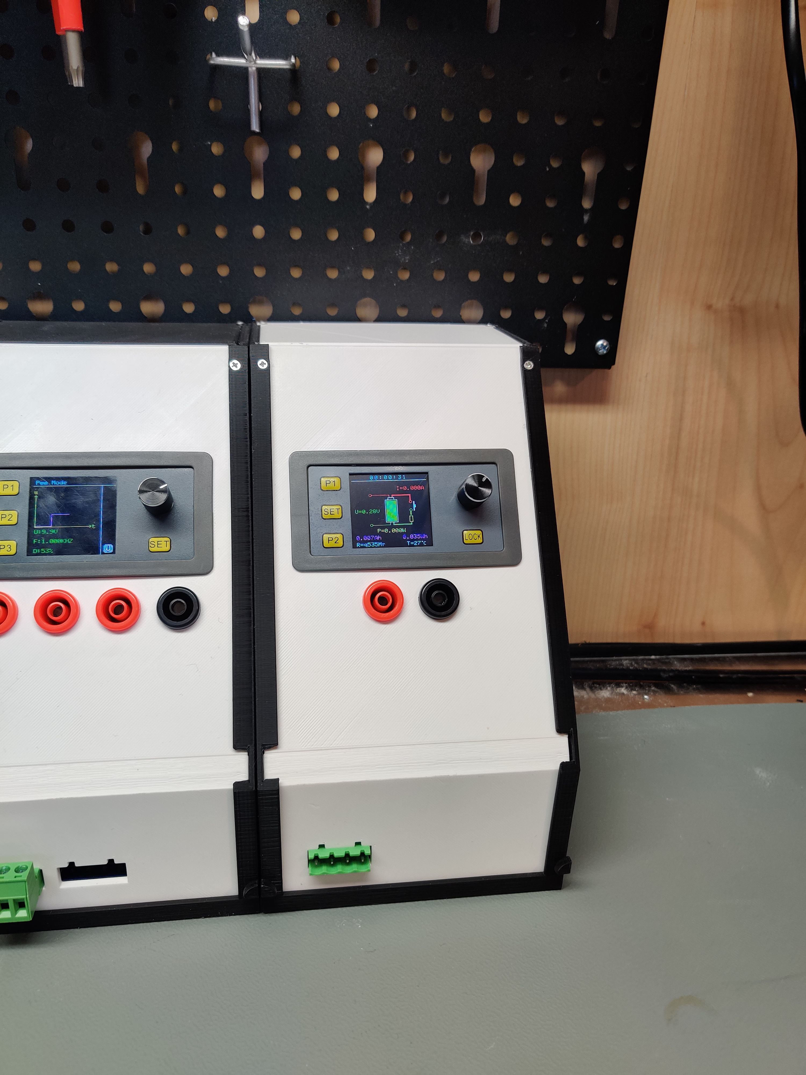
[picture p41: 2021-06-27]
img/ElectronicLoad_Nice2.jpg

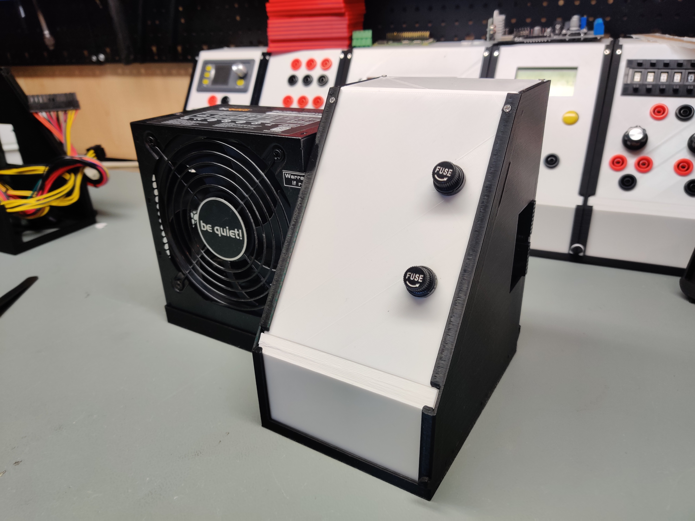
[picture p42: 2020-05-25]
img/ATX_2.jpg

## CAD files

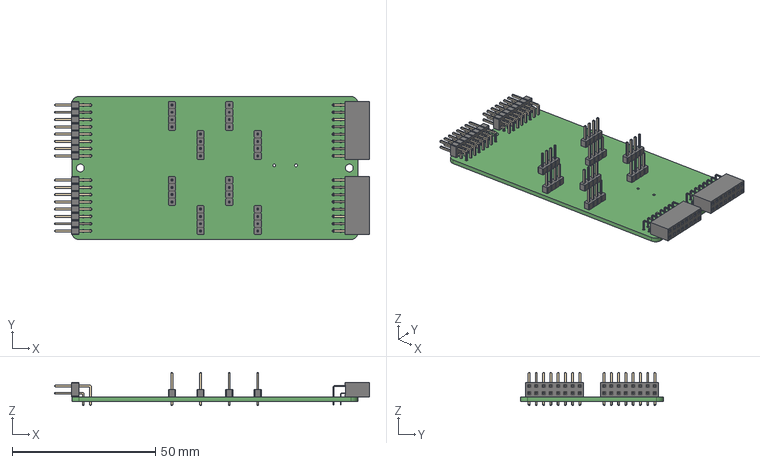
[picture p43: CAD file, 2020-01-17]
PCB_CAD/EleLab_v2_Bus100/3D/EleLab_v2_Bus100.step
110.1 x 50.0 x 11.5 mm

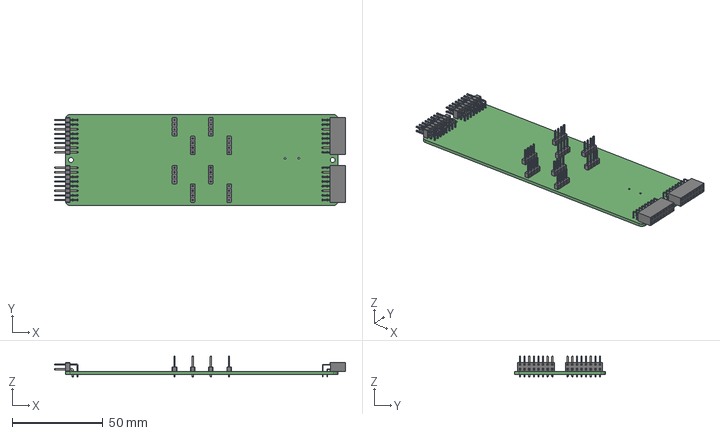
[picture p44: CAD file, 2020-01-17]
PCB_CAD/EleLab_v2_Bus150/3D/EleLab_v2_Bus150.step
160.1 x 50.0 x 11.5 mm

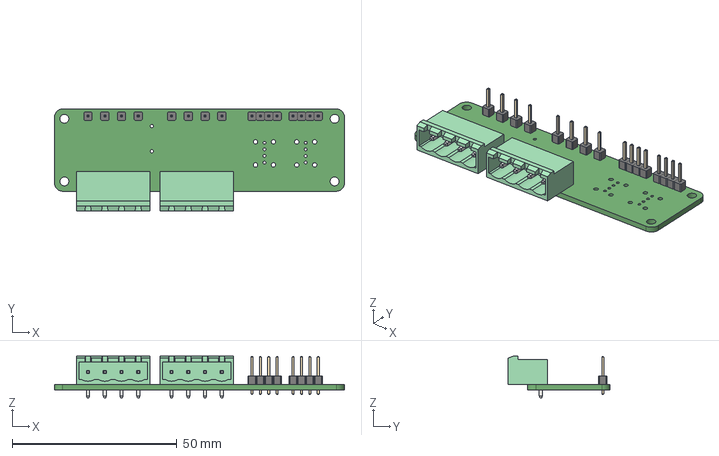
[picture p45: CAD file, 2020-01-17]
PCB_CAD/EleLab_v2_Frontpanel_a/3D/EleLab_v2_Frontpanel_a.step
88.0 x 31.0 x 12.6 mm

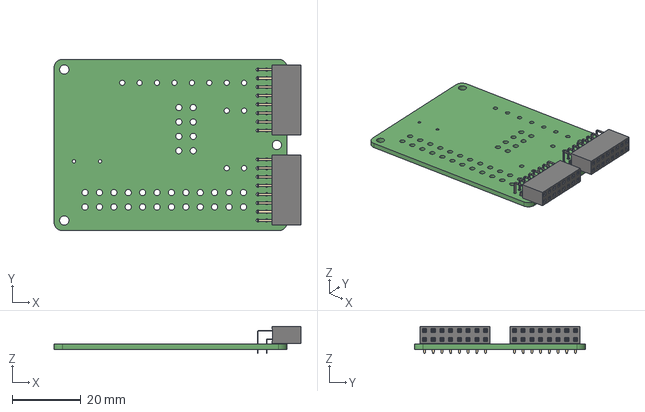
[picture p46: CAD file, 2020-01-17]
PCB_CAD/EleLab_v2_PowerFeed/3D/EleLab_v2_PowerFeed.step
72.0 x 50.0 x 7.98 mm

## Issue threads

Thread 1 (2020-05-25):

Print bed size?

cscott, 2020-05-25:
Nice project!  Would be helpful if you mentioned up top in the README what size print bed is required and/or some options for printing on smaller printers.

Chrismettal, 2020-05-25:
Good idea. I just updated the README with some general printer considerations.
In the future i might go and split the very large print files, namely the ATX and SFX supply modules, as they approach the boundary box of Prusa machines in the X direction, which i alway count as the standard median printer.

Closed 2020-05-25.

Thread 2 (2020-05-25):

What is binary_6?

cscott, 2020-05-25:
There's a component labelled binary_6 on many of your boards, but it doesn't seem to be populated in any of the pictures.  What is it?

(I'm guessing a bypass cap?)

Chrismettal, 2020-05-25:
The "Binary_6" thing is just the logo i put on all my boards. It is not a component to be populated.

Closed 2020-05-25.

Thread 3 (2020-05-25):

Raspbery pi module?

cscott, 2020-05-25:
It might be nice to add a Raspberry Pi module, with a small display and maybe even a trackpad, so you could do basic "look up on the internet", "I need a calculator", or "toggle this GPIO" tasks.

Chrismettal, 2020-05-25:
Yeah a display module is certainly in the works. I don't think i'll couple Rpi and display in the same module but rather have them as two modules next to each other so each of them can be used on its own. But yeah, gonna do that eventually.

Chrismettal, 2021-06-27:
RPi as well as display module now finished. That took a while didn't it?

Closed 2021-06-27.

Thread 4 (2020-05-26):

PCB files?

Ajb2k3, 2020-05-26:
What program did you use to make the PCBs?
I would like to import into easy eda but just get file error trying to import file.

Chrismettal, 2020-05-27:
I made the PCBs in KiCAD. EasyEDA is a PCB designer right? I don't know the import functions of EasyEDA, but i just recloned and retried to upload the gerbers for all the PCBs to jlcpcb for example and the gerbers all worked. Are you trying to edit the PCB designs? If so you might be better off just downloading KiCAD (open source btw) than trying to import it into another designer.
Mind sharing what you are trying to edit?

Ajb2k3, 2020-05-27:
I use Fritzing or easyeda for panel pcbs.
I downloaded the zip but osx opens the zip automatically and if I try to recompress and import I get file read error (Not edited the files yet!)
I've got KiCad on download so will see.
I'm working on some designs for a system powered by a solar panel but I need to add a booster to get the 12v up to 24v for some devices. I also need to add a fuseboard module and modules for powering a mini 3d printer and a mini laser engraver.

Chrismettal, 2020-05-27:
I did not put any zips into the repo itself, just the raw gerber files in a single "Gerber" folder per PCB. Do you clone the whole repo and zip the "Gerber" folder yourself or are you downloading individual files?

I like your ideas for new modules! Especially the fuseboard. I opted for a PowerFeed PCB with front panel fuses for better access as i did not want to populate too many components on the PCB itself for rebuilding purposes. But please share your edits. Would be happy to adopt working new designs into this repo.

Ajb2k3, 2020-05-27:
Will be a pleasure to share my designs into your hub.

Got kicad and rearchived from kicad and its working again.
The fuseboard is just to make a clean version for automotive fuse holders.
I'm going to use the Powerfeed as a mains "Backup" supply

Chrismettal, 2020-05-27:
Great! I'm looking forward to your design.

Ajb2k3, 2020-05-28:
I was trying to import into easyeda as I use easy Eda and fritzing. I am
trying to design a pCD board to connect to my solar setup but using a boost
converter to get 24v. If I make a working pcb I would be happy to share for
you to add to the project. I also need a corner pcb.

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

Closed 2020-05-27.

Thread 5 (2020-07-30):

Multimeter module?

adelkheniche, 2020-07-30:
A workbench multimeter can be helpful too it Will be great to have it integrate in a module less cable everywhere when we are using it

Chrismettal, 2020-08-29:
That is a nice idea. I struggle to find suitable multimeter modules though. I don't think it would be helpful to just have these little voltage displays that you put in your car to monitor your battery. Do you have a nice module in mind?

Chrismettal, 2021-06-07:
Can't find a good multimeter module that would make sense in this. Only cheap voltage meters are available which i don't find helpful at all.

Closed 2021-06-07.

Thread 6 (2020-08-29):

24V in + and gnd linked together.

Ajb2k3, 2020-08-29:
just noticed on the powerfeed board that +24v in and gnd 24v are linked together.
I recommend these pins are seperated to prevent confusion.

Sorry been too busy to work on it.

Chrismettal, 2020-08-29:
Can you explain what exactly is your problem with this?

There are two 24 V terminals labeled as such and there is no designated "24 V gnd". I designed this so i can put 24 V into the bus but also have a terminal where i can connect the DC-DC converters to for the other voltages.

If you are inputting 24 V , you usually won't be populating the ATX connectors, so then you would use the left side of the ATX 8pin for ground as labeled.

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

Closed 2020-11-08.

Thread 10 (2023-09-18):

Gitlab link is to wrong repo.

ScaredyCat, 2023-09-18:
The gitlab link (linked from printables)

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

 links to the wrong github repo.

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

and should link to

https://github.com/Chrismettal/EleLab_v2

Chrismettal, 2023-09-18:
Good catch, thank you! Updated both occurences (Linking from Printables here directly, as well as correctly linking from GitLab to Github)
Which was fun.. Thanks Prusa for not having an API to mass update descriptions.

Closed 2023-09-18.

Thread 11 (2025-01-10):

Is Base100_Carrier.stl supposed to cover Base100_Frame.stl?

datajango, 2025-01-10:
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

Is Base100_Carrier.stl supposed to be a floor for Base100_Frame.stl because it does not fit.

Chrismettal, 2025-01-10:
The "Carrier" bodies are not fully covering floors, they are carrier planes that snap into the frames to carry additional PCBs. They don't do anything by themselves and would need mounting hardware designed on them for example.

They are optional and if you don't know what to do with it, you do not need to print one.

Can you share what you mean with "does not fit" as it appears to fit as designed for me?

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

datajango, 2025-01-10:
by does not fit, I mean the base plates "carriers" do not cover the base fully.    I could they be redesigned to actually cover the entire floor?
can you send me parts lists to order all the components?

also... I was thinking.  perhaps the frames could be redesigned to have modular floors (carriers) with stand offs?

Chrismettal, 2025-01-10:
> by does not fit, I mean the base plates "carriers" do not cover the base fully.

Correct. It was never intended to cover the entire floor.

---

>  can you send me parts lists to order all the components?

The parts lists are found under the respective modules / PCBs in `README.MD`:

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

---

>  perhaps the frames could be redesigned to have modular floors (carriers) with stand offs?

Sure, feel free to redesign!

datajango, 2025-01-11:
I installed FreeCad, I see the frames have filled in bottoms, then you added cutouts

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

Chrismettal, 2025-01-11:
That statement is true.

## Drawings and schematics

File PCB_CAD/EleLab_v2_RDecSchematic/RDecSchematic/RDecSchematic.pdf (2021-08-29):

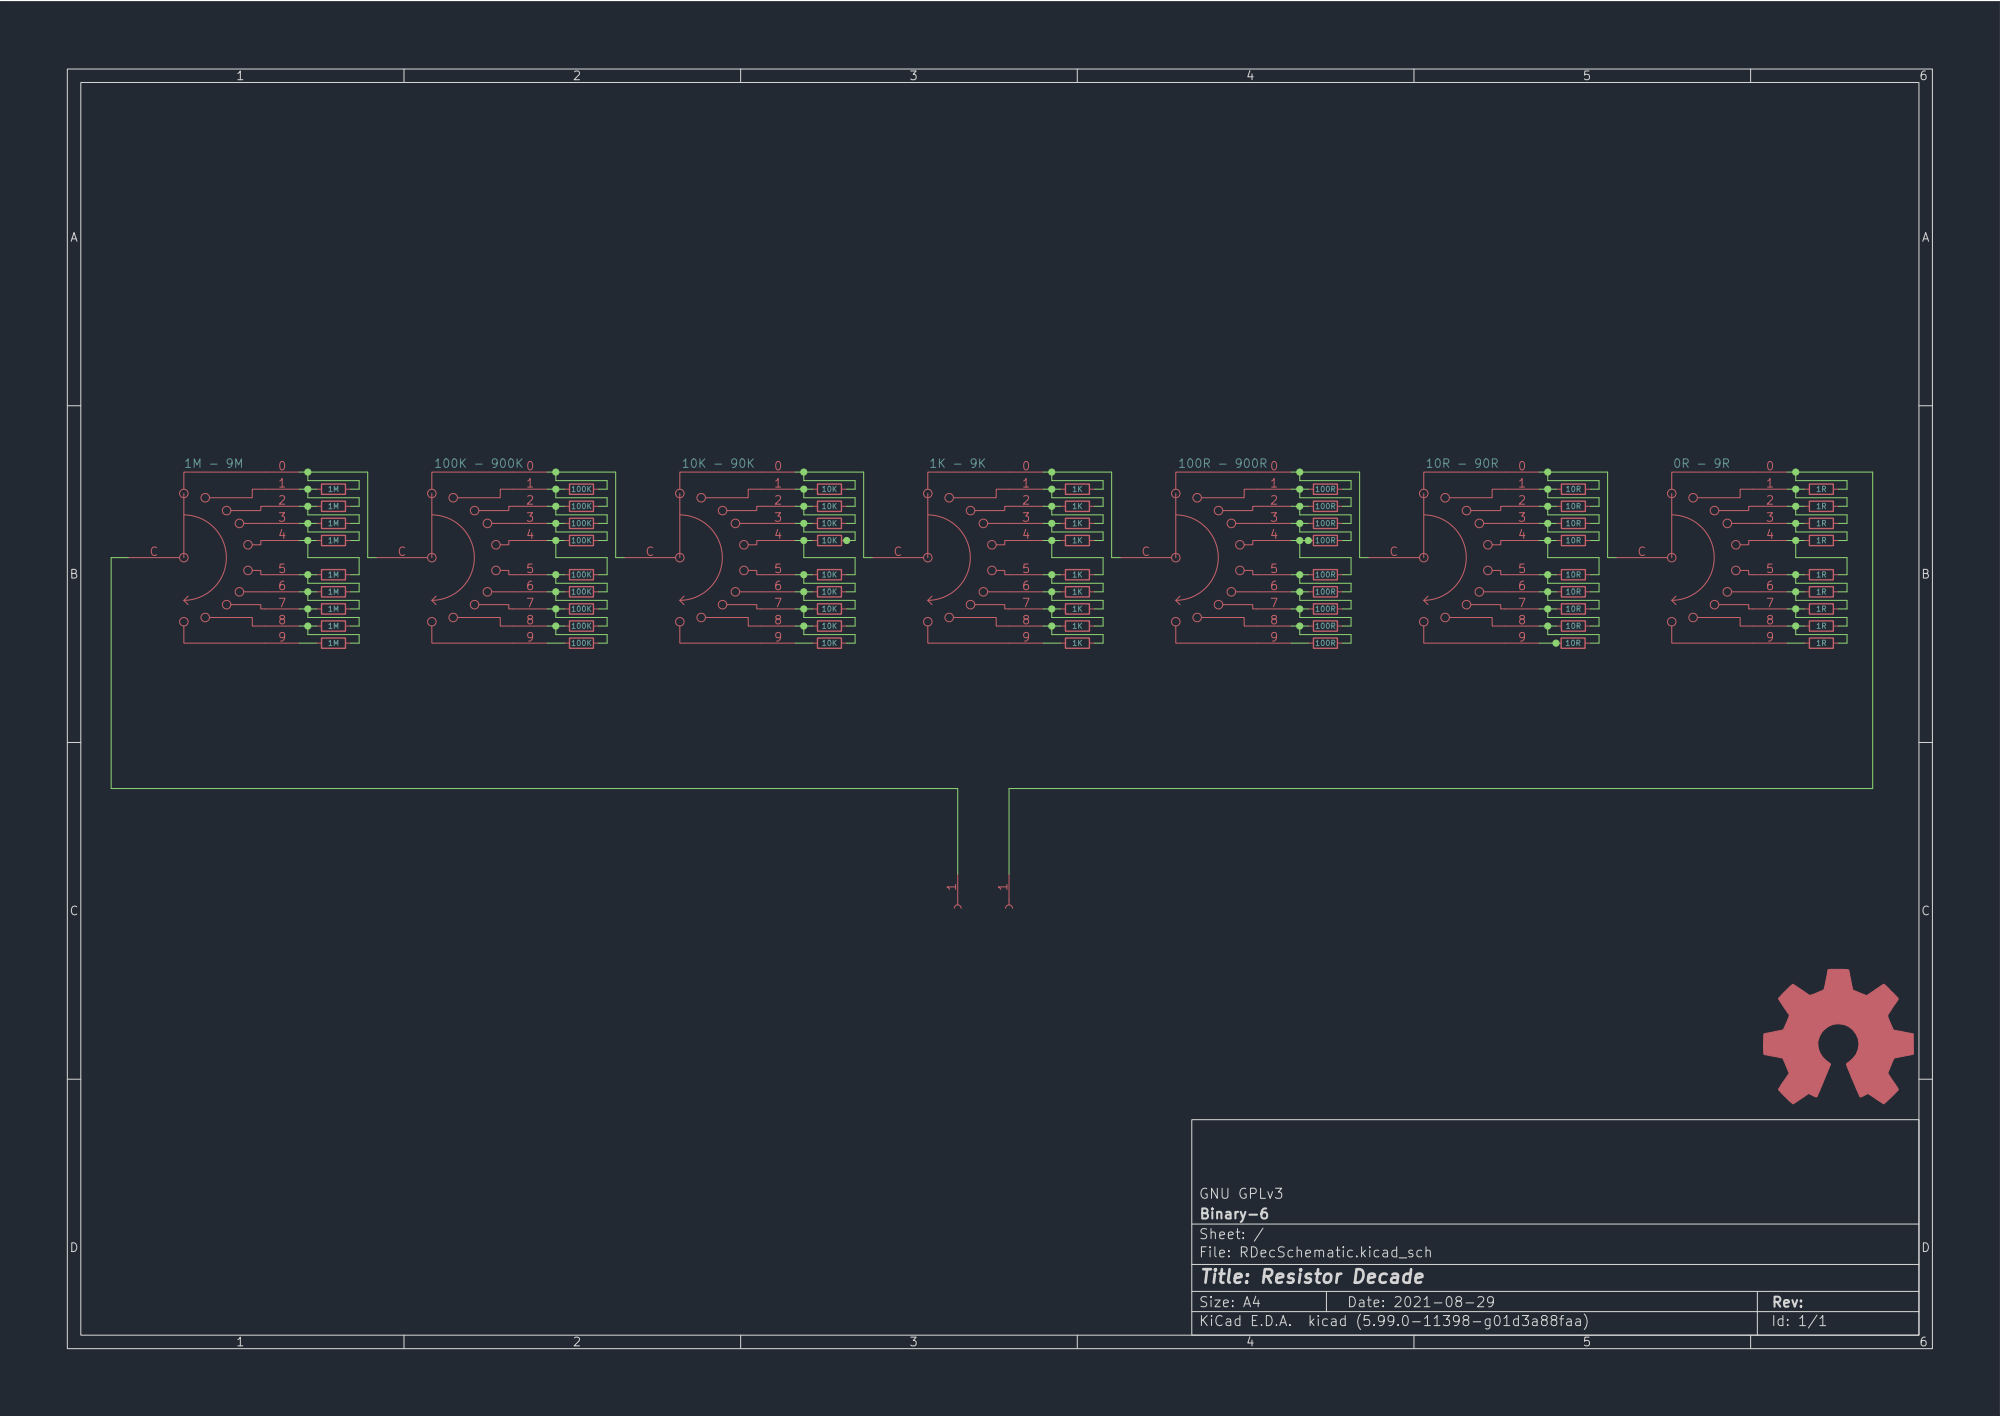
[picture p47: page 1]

File: RDecSchematic.kicad_sch Sheet: / Binary-6 GNU GPLv3

Id: 1/1 Title: Resistor Decade

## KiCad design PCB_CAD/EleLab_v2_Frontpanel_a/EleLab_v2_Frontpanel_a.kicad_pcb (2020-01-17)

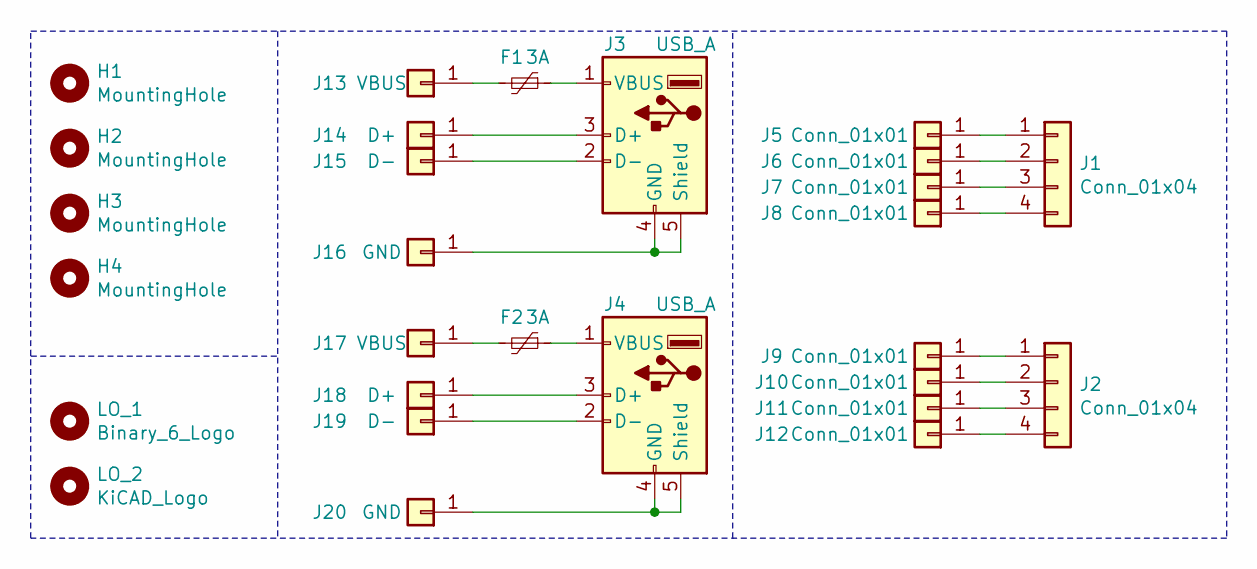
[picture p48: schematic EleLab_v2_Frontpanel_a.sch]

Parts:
F1, F2: 3A; Fuse_0805_2012Metric_Pad1.15x1.40mm_HandSolder
H1, H2, H3, H4: MountingHole; EigenesMountingHole_2.7mm_M2.5
J1, J2: Conn_01x04; PhoenixContact_MSTBA_2,5_4-G-5,08_1x04_P5.08mm_Horizontal
J3, J4: USB_A; USB_B_Standing
J5, J6, J7, J8, J9, J10, J11, J12: Conn_01x01; PinHeader_1x01_P2.54mm_Vertical
J13, J17: VBUS; PinHeader_1x01_P2.54mm_Vertical
J14, J18: D+; PinHeader_1x01_P2.54mm_Vertical
J15, J19: D-; PinHeader_1x01_P2.54mm_Vertical
J16, J20: GND; PinHeader_1x01_P2.54mm_Vertical
LO_1: Binary_6_Logo; Binary_6_v0.1
LO_2: KiCAD_Logo; Symbol_KiCAD-Logo_CopperAndSilkScreenTop

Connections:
unnamed: F1.1, J3.1 (VBUS)
unnamed: F1.2, J13.1
unnamed: F2.1, J4.1 (VBUS)
unnamed: F2.2, J17.1
unnamed: J1.1, J5.1
unnamed: J1.2, J6.1
unnamed: J1.3, J7.1
unnamed: J1.4, J8.1
unnamed: J2.1, J9.1
unnamed: J2.2, J10.1
unnamed: J2.3, J11.1
unnamed: J2.4, J12.1
unnamed: J3.3 (D+), J14.1
unnamed: J3.2 (D-), J15.1
unnamed: J3.4 (GND), J3.5 (Shield), J16.1
unnamed: J4.3 (D+), J18.1
unnamed: J4.2 (D-), J19.1
unnamed: J4.4 (GND), J4.5 (Shield), J20.1

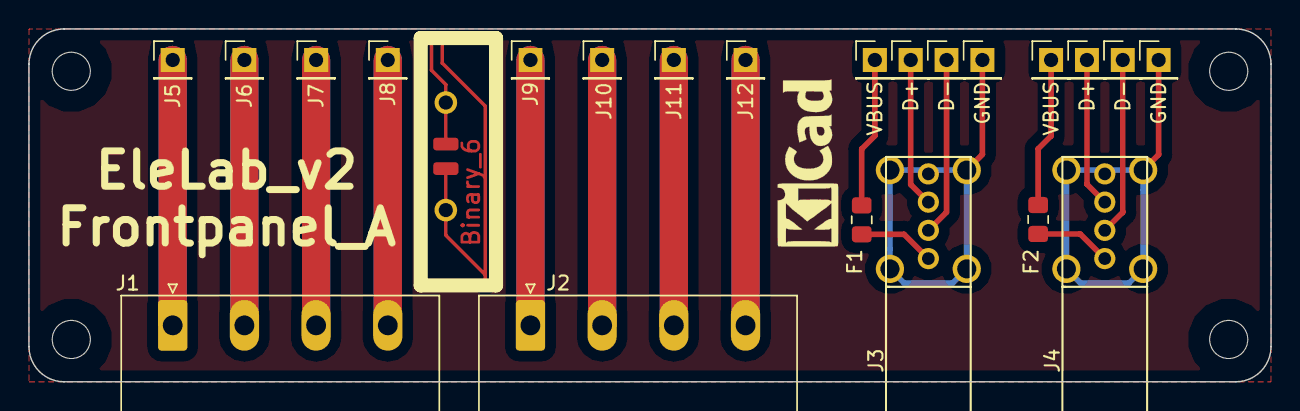
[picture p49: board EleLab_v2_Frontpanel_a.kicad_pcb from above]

Board: 2 copper layers, 88.0 x 25.0 mm, 28 parts (0 on the bottom side), 18 nets.

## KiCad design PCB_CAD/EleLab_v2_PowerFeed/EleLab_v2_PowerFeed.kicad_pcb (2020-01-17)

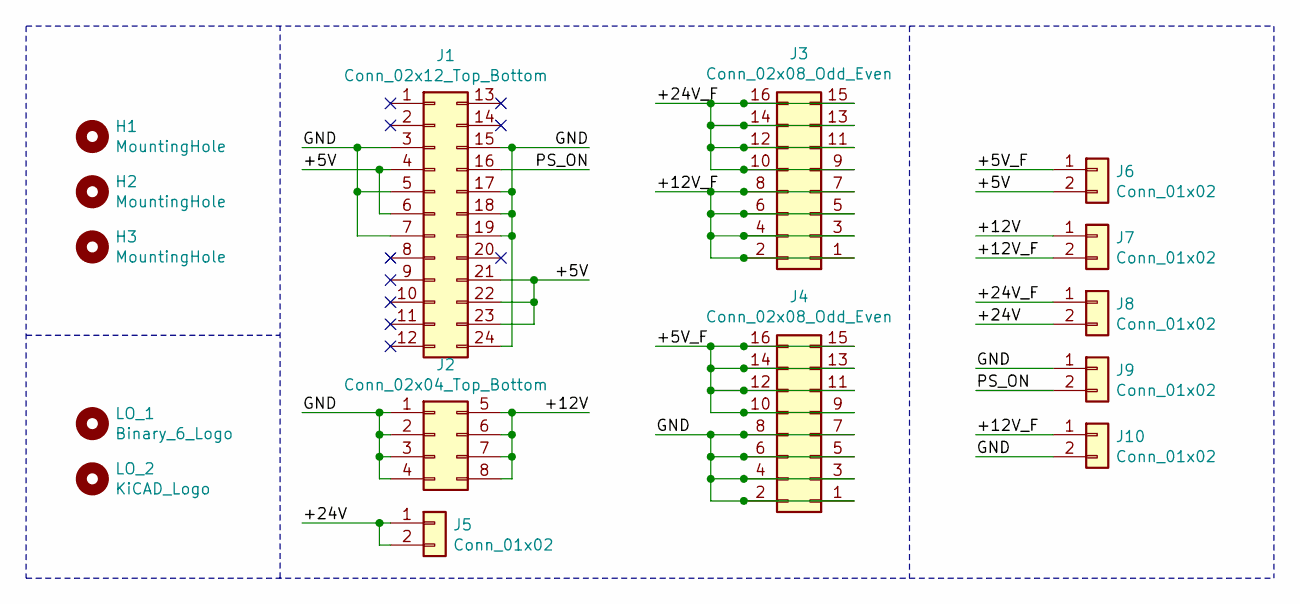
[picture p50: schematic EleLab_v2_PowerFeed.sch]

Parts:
H1, H2, H3: MountingHole; EigenesMountingHole_2.7mm_M2.5
J1: Conn_02x12_Top_Bottom; Molex_Mini-Fit_Jr_5566-24A_2x12_P4.20mm_Vertical
J2: Conn_02x04_Top_Bottom; Molex_Mini-Fit_Jr_5566-08A_2x04_P4.20mm_Vertical
J3, J4: Conn_02x08_Odd_Even; PinSocket_2x08_P2.54mm_Horizontal_NoSilk
J5, J6, J7, J8, J9, J10: Conn_01x02; TerminalBlock_bornier-2_P5.08mmNoSilk
LO_1: Binary_6_Logo; Binary_6_v0.1
LO_2: KiCAD_Logo; Symbol_KiCAD-Logo_CopperAndSilkScreenTop

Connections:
/+5V: J1.4, J1.6, J1.21, J1.22, J1.23, J6.2
/+5V_F: J4.9, J4.10, J4.11, J4.12, J4.13, J4.14, J4.15, J4.16, J6.1
/+12V: J2.5, J2.6, J2.7, J2.8, J7.1
/+12V_F: J3.1, J3.2, J3.3, J3.4, J3.5, J3.6, J3.7, J3.8, J7.2, J10.1
/+24V: J5.1, J5.2, J8.2
/+24V_F: J3.9, J3.10, J3.11, J3.12, J3.13, J3.14, J3.15, J3.16, J8.1
/GND: J1.3, J1.5, J1.7, J1.15, J1.17, J1.18, J1.19, J1.24, J2.1, J2.2, J2.3, J2.4, J4.1, J4.2, J4.3, J4.4, J4.5, J4.6, J4.7, J4.8, J9.1, J10.2
/PS_ON: J1.16, J9.2

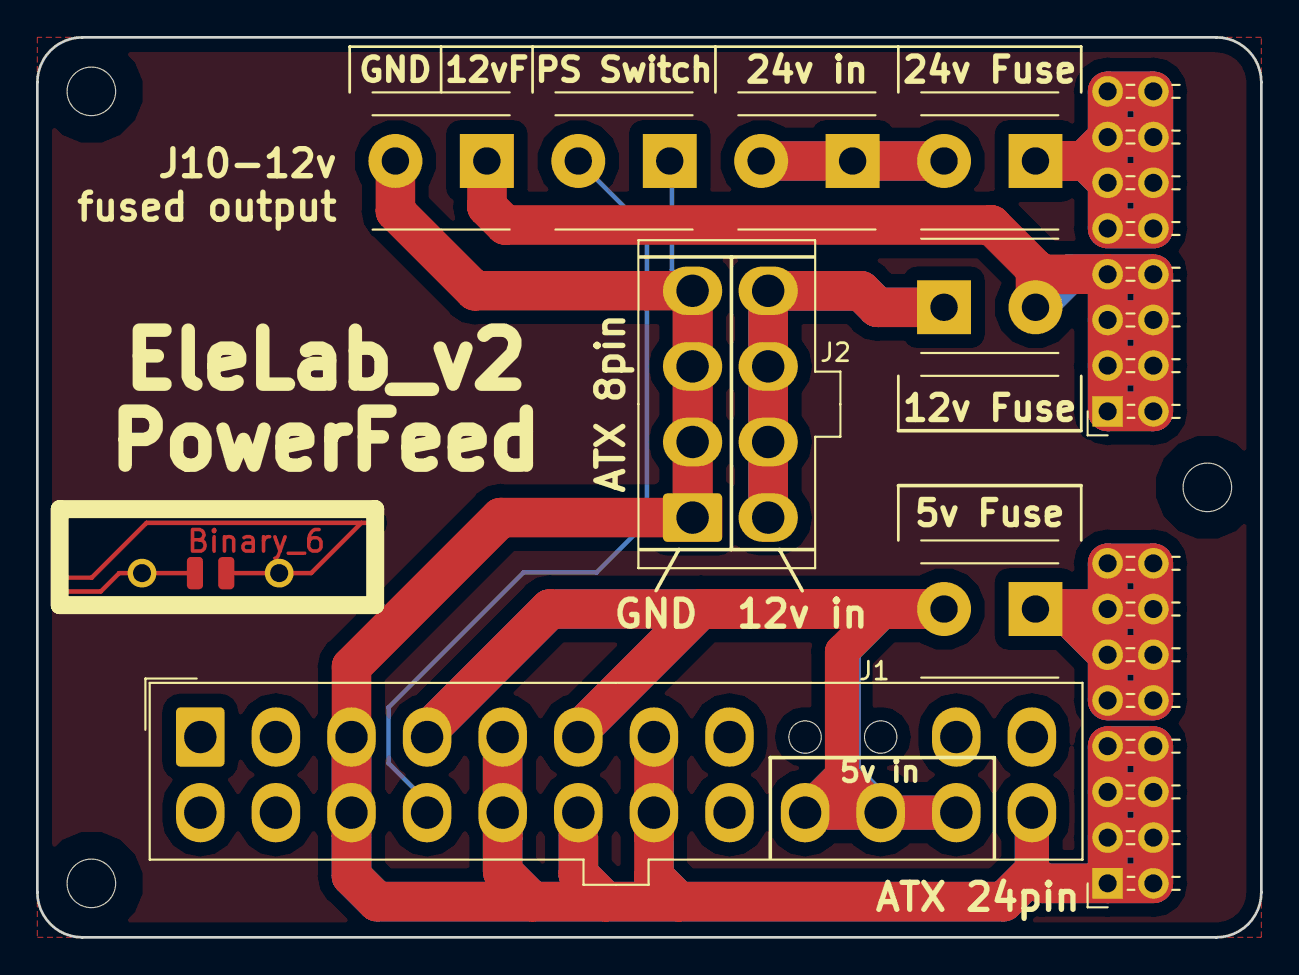
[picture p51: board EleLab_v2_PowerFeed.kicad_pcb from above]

Board: 2 copper layers, 68.0 x 50.0 mm, 15 parts (1 on the bottom side), 8 nets.

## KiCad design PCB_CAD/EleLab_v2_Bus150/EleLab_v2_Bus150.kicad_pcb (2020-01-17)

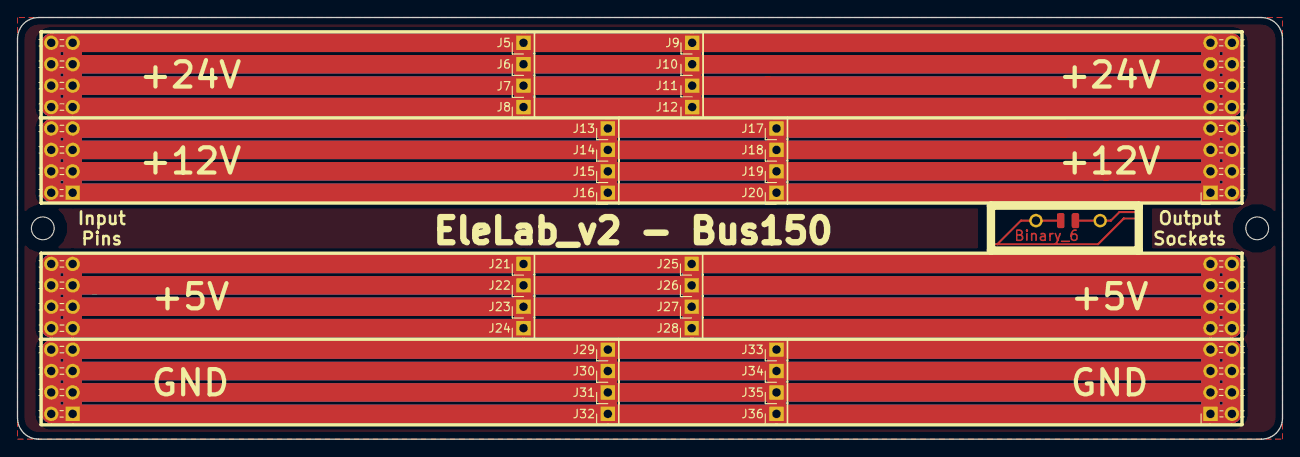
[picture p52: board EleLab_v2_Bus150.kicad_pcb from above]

Board: 2 copper layers, 150.0 x 50.0 mm, 40 parts (1 on the bottom side), 4 nets.

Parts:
H1, H2: MountingHole; EigenesMountingHole_2.7mm_M2.5
J1, J2: Conn_02x08_Odd_Even; PinHeader_2x08_P2.54mm_Horizontal_NoSilk
J3, J4: Conn_02x08_Odd_Even; PinSocket_2x08_P2.54mm_Horizontal_NoSilk
J5, J6, J7, J8, J9, J10, J11, J12: +24 V; PinHeader_1x01_P2.54mm_Vertical
J13, J14, J15, J16, J17, J18, J19, J20: +12 V; PinHeader_1x01_P2.54mm_Vertical
J21, J22, J23, J24, J25, J26, J27, J28: +5 V; PinHeader_1x01_P2.54mm_Vertical
J29, J30, J31, J32, J33, J34, J35, J36: GND; PinHeader_1x01_P2.54mm_Vertical
LO_1: Binary_6_Logo; Binary_6_v0.1
LO_2: KiCAD_Logo; Symbol_KiCAD-Logo_CopperAndSilkScreenTop

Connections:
/+5V: J2.9, J2.10, J2.11, J2.12, J2.13, J2.14, J2.15, J2.16, J4.9, J4.10, J4.11, J4.12, J4.13, J4.14, J4.15, J4.16, J21.1, J22.1, J23.1, J24.1, J25.1, J26.1, J27.1, J28.1
/+12V: J1.1, J1.2, J1.3, J1.4, J1.5, J1.6, J1.7, J1.8, J3.1, J3.2, J3.3, J3.4, J3.5, J3.6, J3.7, J3.8, J13.1, J14.1, J15.1, J16.1, J17.1, J18.1, J19.1, J20.1
/+24V: J1.9, J1.10, J1.11, J1.12, J1.13, J1.14, J1.15, J1.16, J3.9, J3.10, J3.11, J3.12, J3.13, J3.14, J3.15, J3.16, J5.1, J6.1, J7.1, J8.1, J9.1, J10.1, J11.1, J12.1
/GND: J2.1, J2.2, J2.3, J2.4, J2.5, J2.6, J2.7, J2.8, J4.1, J4.2, J4.3, J4.4, J4.5, J4.6, J4.7, J4.8, J29.1, J30.1, J31.1, J32.1, J33.1, J34.1, J35.1, J36.1

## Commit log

2020-01-25 SFX_v2 - less wasted filament, some chamfers and integrated supports
2020-02-09 Removed voltage / current meters from power supply
2020-02-09 First version of 2 voltage fixed supply
2020-02-09 First versions of DSO138 and resistor decade
2020-03-07 Edit CompTest - bigger hole for actuating the lever and actually fit the button.
2020-03-08 Edit DSO138 - add power switch in lower panel.
2020-03-18 Finish 24v supply module
2020-05-25 Add ATX mention to readme and fix ATX screw holes
2020-05-25 Edit readme with printer requirements
2021-06-07 Remove smaller MW supply, add casing and mounting for bigger MW supply
2021-06-07 Add initial, unfinished version of Raspberry Pi module
2021-06-07 Work on RPi module. Far from finished, most measurements just guessed until material arrives
2021-06-09 Add holes for buckets to TS100 module
2021-06-09 Add upper bucket empty
2021-06-09 Add Ãlower bucket empty
2021-06-10 Add upper bucket for soldering sponge
2021-06-10 Add solder holder to lower bucket
2021-06-10 Finish initial version of TS100 module - wait for printing
2021-06-26 Add switch to RPI module and enlarge shield hole on upper panel
2021-06-27 Remove not needed hole from Signalgenerator lower panel
2021-06-27 Make all chinese insert modules like var supply tighter
2021-06-27 Add 30mm fan for ElectronicLoad module to readme
2021-08-29 Add measurements and schematic of RDec
    [RDecSchematic.kicad_sch]
